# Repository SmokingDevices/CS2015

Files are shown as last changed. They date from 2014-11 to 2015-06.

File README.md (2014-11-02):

Welcome ...

we have started the project!

Also GitHub for Windows installieren
- Links oben mit + das neue Repositorie anlegen (bzw. ein vorhandenes suchen)
- vor Änderungen, immer mit online Synchen (rechts oben)
- Wenn Änderungen, dann über Uncommitted changes diese einchecken
- dann rechts oben sync drücken

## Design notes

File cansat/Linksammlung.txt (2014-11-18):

LINKSAMMLUNG

Staubsensor:
	http://shop.boxtec.ch/grove-staub-sensor-p-41117.html

http://www.pollin.de/shop/dt/NzI2OTgxOTk-/Bauelemente_Bauteile/Aktive_Bauelemente/Sensoren_Peltier_Elemente/Staubsensor_SHARP_GP2U06.html

Kamera:

	http://www.preisvergleich.de/search/landing/query/%2BMicro+%2BCam/s/googlem/koid/2315796613/gkaid/91312190/adid/3319103750/gkyid/32237585990/ckw/2315796613x91312190x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

http://www.nuvolashop.com/en/mini-digital-video-recorders/1781-super-mini-digital-video-audio-recorder-640x480-pixels-camera-usb20-port-micro-sd-card-slot.html

	http://ekonline.co.uk/532-997-thickbox/spy-video-camera-keyring-8gb-micro-sd-card.jpg - http://ekonline.co.uk/deal-of-the-week/532-spy-video-camera-keyring-8gb-micro-sd-card.html

http://www.nacrc.com/d001-mini-dv-camera-without-micro-sd-card-720-x-480px-p-594.html
	
	http://www.aliexpress.com/item/Mini-HD720P-8-0MP-digital-video-camera-without-screen-supports-Micro-SD-card-upto-32GB-built/547477856.html

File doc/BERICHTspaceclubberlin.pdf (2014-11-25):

## Endbericht CanSat 2014

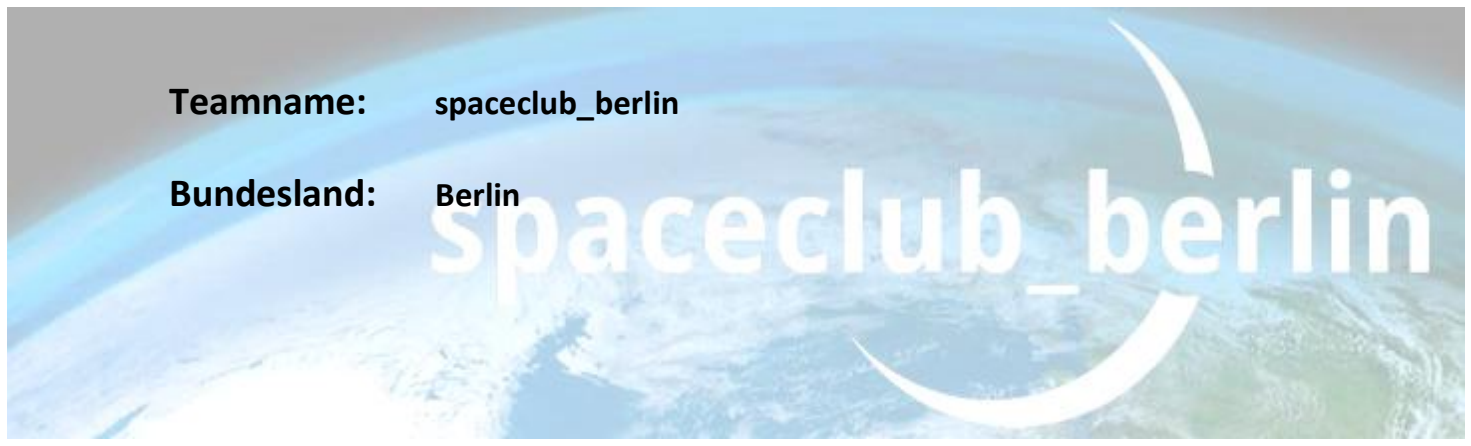
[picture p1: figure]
Teamname:; spaceclub_berlin; Bundesland:; Berlin

1

Inhaltsverzeichnis | Seite
1. | Einleitung | 2
1.1 | Teamorganisation und Aufgabenverteilung | 3
1.2 | Missionsziele | 4
2. | Beschreibung des CanSat | 5
2.1 | Missionsablauf | 5
2.2 | Mechanisches- und Strukturdesign | 6
2.2.1 | Außenkörper | 6
2.2.2 | Innerer Aufbau | 7
2.3 | Elektrische Konstruktion | 11
2.4 | Technische Anforderungen | 14
3. | Ausgangsbedingungen für die Durchführung des Projektes | 17

### 3.1 Physikalische Eigenschaften der Baukomponenten

des CanSat | 17
3.2 | Kosten der verwendeten Baukomponenten | 18
3.3 | Externe Unterstützung | 19
4. | Primäre Mission | 20
4.1 | Missionsziele | 20
4.2 | Dafür benutzte Sensoren bzw. Geräte | 20
4.3 | Ergebnisse | 21
4.3.1 | Temperatursensor | 21
4.3.2 | Drucksensor | 23
5. | Sekundäre Mission | 25
5.1 | Missionsziele | 25
5.2 | Dafür benutzte Sensoren bzw. Geräte | 25
5.3 | Ergebnisse | 26
5.3.1 | Staubsensor | 26
5.3.2 | Kamera mit JPEG-Trigger | 27
6. | Bergungssystem | 28
6.1 | Fallschirm | 28
6.2 | Pieper | 32
6.3 | GPS | 32
6.4 | Bodenstation | 34
6.4.1 | Yagi-Antenne | 34
7. | Fertige Software | 35
8. | Problembehandlung | 45
9. | Öffentlichkeitsarbeit | 47
10. | Reflexion des Wettbewerbes | 49

2

### 1. Einleitung

Unser Team setzt sich aus 3 Mädchen und 2 Jungen zusammen, die sich durch das orbitall im FEZ Berlin und den spaceclub_berlin kennen. Durch gemeinsame Projekte im spaceclub_berlin, aber auch in den Spacecamps 2012 und 2013 oder auch in Jugend forscht, sind wir ein eingespieltes Team geworden. Betreut und unterstützt werden wir von Mitarbeitern des orbitall und erfahrenen Programmierern.
Das Projekt hat uns durch einen Vortrag von Frau Remeikis besonders angezogen. Sie hat uns im spaceclub_berlin detailliert über die Anforderungen des Wettbewerbes informiert und uns dazu animiert, selber daran teilzunehmen. Motiviert uns zu präsentieren und uns neuen Herausforderungen zu stellen, haben wir uns in einem Team von 5 Mitgliedern zusammengefunden. Bei unseren spaceclub-Treffen haben wir uns erstmals an das Thema herangeschlichen und uns beraten, wie wir herangehen wollen. Als nächstes haben wir Mitarbeiter gefragt, unsere Betreuer und Lehrkräfte zu sein und uns über die Technologie des CanSat zu unterrichten. Einige unserer jetzigen Betreuer haben ihre Hilfe zudem selbst angeboten, zum Beispiel auf dem Gebiet des Programmierens. Zu den weiteren Treffen haben wir uns Ziele gesetzt, die wir erreichen wollen, haben uns weitergebildet und gelernt, letztendlich die Komponenten programmiert, konstruiert und zusammengeführt.
Natürlich haben sich während der Zeit viele Probleme aufgetan, die uns viel Zeit gekostet haben. Nichtsdestotrotz haben wir weiter gearbeitet und sind mit Hilfe unserer Betreuer weiter gekommen. Problemszenarien haben wir durchgespielt und sicher gestellt, dass die Startvorbereitung und der Start erfolgreich von statten gehen.
Während der Erarbeitung haben wir viel Material gesammelt und uns mit Experten ausgetauscht. Außerdem wurden wir mit dem Bereich des Programmierens bekannt gemacht und haben die Konstruktion geplant und ausgeführt. Alles mit dem Hintergedanken den Flug erfolgreich durchführen zu können und möglichst wenig Materialschäden davon zu tragen.
Der Wettbewerb startete für uns im Februar 2014 und endet im Oktober 2014 mit dem Start der Rakete und dem Fall des CanSats.
Die Besonderheit unseres CanSats ist die Komplexität der Systeme, die Sekundärmission und unsere Konstruktion. Wir haben nur wenige Komponenten unverändert gelassen und haben somit an viel Platz und Gewicht gespart.

3

### 1.1 Teamorganisation und Aufgabenverteilung

Das Team setzt sich aus uns fünf Teammitgliedern (T1-T5) mit entsprechender Aufgabenverteilung, sowie den Betreuern (B1-B4) und den Helfern (H1- H3) zusammen.

Tabelle 1: Teamorganisation und Aufgabenverteilung
NO | Name | Position
T1 | Christina Nadolsky | Teamleitung; Bau des CanSat; Datengewinnung, Softwareentwicklung
T2 | Yuna Reinhardt | Dokumentation; Kontrolle der Einhaltung der Wettbewerbsbedingungen; Leitung der Testverfahren, Softwareentwicklung
T3 | Adrian Melinat | Fallschirm; Abpufferung des CanSats bei der Landung
T4 | Nana Reinhardt | Bau des CanSat; Datengewinnung, Erstellung der Grafiken, Softwareentwicklung
T5 | Christian Staudigl | Entwicklung der Software, Innere Anordnung der Komponenten
B1 | Sylvia Reinhardt | Betreuerin
B2 | Werner Bachmann | Betreuer, Unterstützung bei der Fallschirmkonstruktion
B3 | Steffen Janke | Berater für die Entwicklung der Software und innere Anordnung der Komponenten
B4 | Jan Klug | Unser Ausbilder für Softwareentwicklung
H1 | Uwe Lathan | Technischer Berater
H2 | Jörg Briesemeister | Beratung bei der Konstruktion
H3 | Jürgen Kittel | Herstellung der Platinen

4

### 1.2 Missionsziele

Der CanSat-Wettbewerb stellt zur Aufgabe, einen Satelliten zu entwickeln, diesen zu bauen und zu programmieren. Er soll zwei Missionen erfüllen, zum einen die vorgegebene Primärmission und zum anderen die selbst wählbare Sekundärmission. Der Satellit wird mit Hilfe einer Rakete auf eine Höhe von bis zu 1000m gebracht und von der Rakete ausgeworfen. Dann fällt der CanSat zurück auf den Boden, wobei er dabei Messungen durchführt.
Bei der Primären Mission ist es unsere Aufgabe, die Temperatur und den Druck zu messen. Das werden wir mit zwei unterschiedlichen Sensoren tun (siehe dazu 4.). Wenn wir die Daten der Temperatur in Höhe von einem Kilometer erhalten haben, werden wir daraus ein Temperaturprofil erstellen. Daraus können wir dann ablesen, wie sehr die Temperaturen in dieser Höhe sich mit denen auf dem Boden unterscheidet und wie sehr sie abfällt / schwankt.

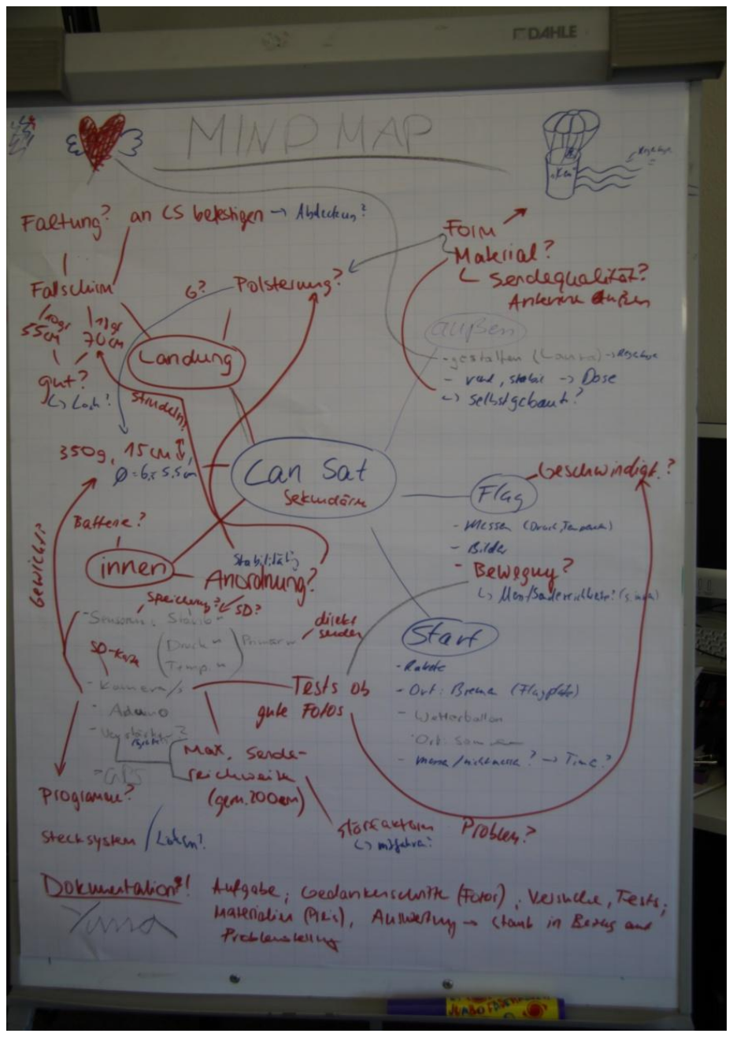
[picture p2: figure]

Bild 1: unser erster Missionsplan für den CanSat

In unserer Sekundären Mission werden wir die Staubkonzentration in der Luft messen. Wir bauen einen Sensor für Ermittlung der Staubkonzentration in der Atmosphäre ein, um diese in Abhängigkeit von der Flugrichtung und Flughöhe zu ermitteln. Gleichzeitig werden wir mit einer Kamera Fotos von dem überflogenen Ort machen, so dass wir die gemessene Staubkonzentration dem Ort (Fabrik, Wald, Autobahn...) zuordnen können. Um die aktuellen Messpunkte noch weiter zu belegen, werden auch die Lagedaten des Satelliten über GPS erfasst. Dies hilft uns auch, den Satelliten zu bergen.

5

### 2. Beschreibung des CanSat

Unser Cansat beinhaltet neben dem CanSat Kit, in dem zwei Temperatursensoren und ein Drucksensor vorhanden sind, verschiedene weitere Bauteile, wie ein Staubsensor, GPS, ein Pieper, und eine Kamera mit Speichermöglichkeit der Bilder auf einem JPEG Trigger (siehe Grafik 1). Die gesendeten Daten der beiden Temperatursensoren, des Drucksensors, des Staubsensors und des GPS werden am Empfängermodul in der Bodenstation mit einer Yagi-Antenne verstärkt. Die Antenne ermöglicht es, Signale aus weiteren Entfernungen besser empfangen zu können.

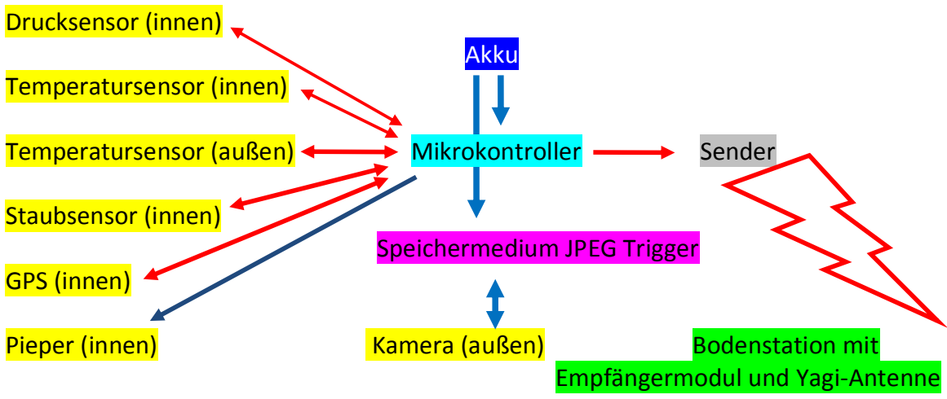
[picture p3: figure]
Drucksensor (innen); Akku; Temperatursensor (innen); Temperatursensor (außen); Mikrokontroller; Sender; Staubsensor (innen); Speichermedium JPEG Trigger; GPS (innen); Pieper (innen); Kamera (außen); Bodenstation mit; Empfängermodul und Yagi-Antenne

Grafik 1: schematische Beschreibung des Aufbaus und der Funktionsweise des CanSat

### 2.1 Missionsablauf

Die Mission wird folgendermaßen ablaufen:
Vor dem Start überprüfen wir die Sensoren, ob sie funktionstüchtig sind. Wir werden die entsprechende Sendefrequenz mit Hilfe des vorgegebenen Programms einstellen. Dann werden wir den Fallschirm überprüfen, ob er beim Transport oder ähnlichem beschädigt wurde und ob er nicht richtig in Position liegt. Sollte dies der Fall sein, wird er ausgetauscht oder richtig positioniert.
Die Notwendigkeit dieser Vorkehrungen beruht auf der Komplexität des CanSat. Da alle Komponenten miteinander in Verbindung stehen, kann der Ausfall einer Komponente zu einem Ausfall fast aller führen. Zum Beispiel wenn die Akkus ausfallen oder auf dem Mikrokontroller ein Kurzschluss entsteht. Wir haben aber sichergestellt, dass sich die Komponenten nicht während des Fluges verändern, sie sind also gepolstert und gesichert. Wichtig ist, dass wir zuerst den Empfänger starten und dann den CanSat, da wir am Anfang der Datenübertragung eine relevante Kopfzeile bekommen.
Der Start des CanSat wird mit einer vorgegebenen Rakete ermöglicht. Der Satellit wird in die Rakete angebracht, der Schalter an der Unterseite des CanSat betätigt, wodurch er zu senden beginnt. Nach ca. 1000 m wird der CanSat von der Rakete gelöst und der Fallschirm geht auf. Nun sinkt er mit einer Fallgeschwindigkeit von 15 Meter pro Sekunde zu Boden. Währenddessen werden die Daten an die Bodenstation gesendet und dort mit einer Yagi-

6

Antenne, die zur Verstärkung des Empfängermoduls angebracht wurde, empfangen. Die Kamera speichert über einen JPEG-Trigger die Bilder auf einer SD-Karte im CanSat.
Die empfangenen GPS-Daten können dann zur Ermittlung der Landestelle genutzt werden, wenn sie sich also über einen längeren Zeitraum nicht mehr ändern und die Höhe des Drucksensors nicht variiert, können wir uns auf die Suche machen. In der Bodenstation müssen nun die gemessenen Daten gespeichert werden. Zur Lokalisation hilft uns ein zweites GPS-Gerät, das mit der Bodenstation verbunden ist. Erkennbar ist der Fallschirm und das glitzernde Wimpel durch grelle Farben und zusätzlich gibt der eingebaute Pieper einen Ton von sich.
Die SD-Karte wird nun entnommen und die darauf gespeicherten Textdateien in Bilder umformatiert. Nun können wir zu den Daten der Sensoren auch Bilder der Umgebung zufügen. Schlussendlich müssen die gemessenen Ergebnisse ausgewertet werden. Diese Auswertung wird dann in unsere Präsentation am Tag nach dem Start mit einfließen.

### 2.2 Mechanisches- und Strukturdesign

Das mechanische- und Strukturdesign setzt sich aus dem Außenkörper und dem inneren Aufbau zusammen.

### 2.2.1 Außenkörper

Anfangs hatten wir uns für einen Außenkörper aus Carbonfaser entschieden. Die Röhre aus diesem Material ist sehr stabil, hatte jedoch den Nachteil, dass ihr Durchmesser nur 60mm war und wir somit auf die Maße (Höhe x Durchmesser) von 115mm x 60 mm kamen. Bei dem Bau des CanSat und der Unterbringung der verschiedenen Bauteile konnten wir nicht auf die fehlenden 6mm verzichten. Die Unterbringung des JPEG-Triggers und der Staubsensors war in dieser engen Röhre nicht möglich, so dass wir uns für ein anderes Material für die Außenhülle des CanSat entschieden haben.
Die Außenhülle ist ein zylindrischer Körper aus Plastik mit den Maßen (Höhe x Durchmesser): 115 mm x 66 mm und zwei Deckeln aus Plexiglas. Sie hat eine milchige Farbe und ist leicht durchlässig (siehe Bild 3).
Der untere Deckel besitzt insgesamt 14 Löcher: darunter 2 Löcher zur Befestigung der inneren Stangen, 3 für den Hauptschalter und seine Befestigung, einen für die Kamera und 5 zur Luftzufuhr für den Staubsensor, welche in einem Kreis angeordnet sind, und eins neben dem Hauptschalter, durch das der NTC (äußerer Temperatursensor) geführt wird.
Der obere Deckel hat 19 Löcher (siehe Bild2). Hierbei handelt es sich um 16, in einem Kreis angeordneten Löcher zur Befestigung des Fallschirms, welcher durch das eine Loch geführt wird und bei dem entsprechenden nebenliegenden Partner hinausgeführt wird. Desweiteren gibt es nur ein Loch für die Luftabgabe, die während des Fluges den CanSat durchströmt. Wir wollen damit einen bestimmen Luftdruck am oberen Deckel entstehen lassen, wodurch dies Luft mit höherer Geschwindigkeit hinaus bläst und der Fallschirm sich möglichst schnell öffnet. Die letzten beiden Löcher sind für zur Befestigung des Deckels mit den inneren Stangen, also für Schrauben vorgesehen.

7

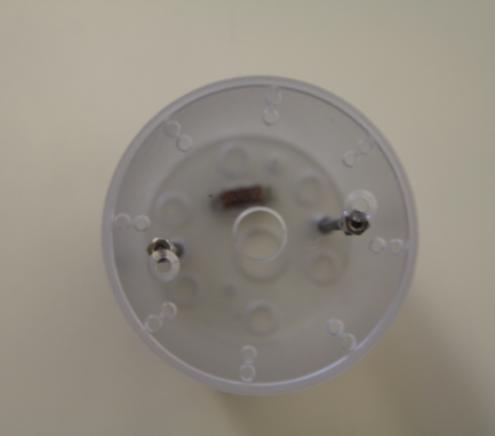
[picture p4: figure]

Bild 2: Oberseite des CanSat mit Durchblick | Bild 3: Seitenansicht des CanSat
zur Unterseite

### 2.2.2 Innerer Aufbau

Der Aufbau des CanSat (siehe Bild 4) basiert auf einem horizontalen Schichtsystem der Komponenten, welche an zwei vertikalen Stangen befestigt sind. Am unteren Teil des CanSat befindet sich unsere Kombination aus Kamera und JPEG-Trigger (siehe Bild5 und Bild6), mit einem großen Loch im unteren Deckel für die Linse der Kamera. Mit einem geringen Abstand von dem JPEG-Trigger wird horizontal darüber der Staubsensor platziert. Die Luft strömt durch die unteren Löcher in den CanSat hinein, durch den Staubsensor und durch die oberen Löcher wieder hinaus. Ebenfalls mit etwas Abstand zur Gewährleistung der Luftzufuhr befindet sich die Dreierkombination aus Sender, Mikrokontroller und Platine mit den Sensoren für Druck, Temperatur (innen), GPS, Pieper und den Anschlüssen zur Stromversorgung der Kamera und des Staubsensors. Der Temperatursensor (außen) ist ebenfalls an der Platine durch lange Kabel befestigt, die nach unten geführt den Sensor neben der Kamera aus einem kleinen Loch am Deckel ragen lassen.
Um Platz zu sparen, werden die Akkus, die ebenfalls mit dem Mikrokontroller verbunden sind, in die Hohlräume zwischen der Dreierkombination gelegt und mit Schaumstoff abgepolstert. Die Elemente sind mit Abstandsschrauben voneinander getrennt. Weitere Polsterungen sind kaum möglich, da der Staubsensor eine ausreichende Luftzufuhr benötigt.

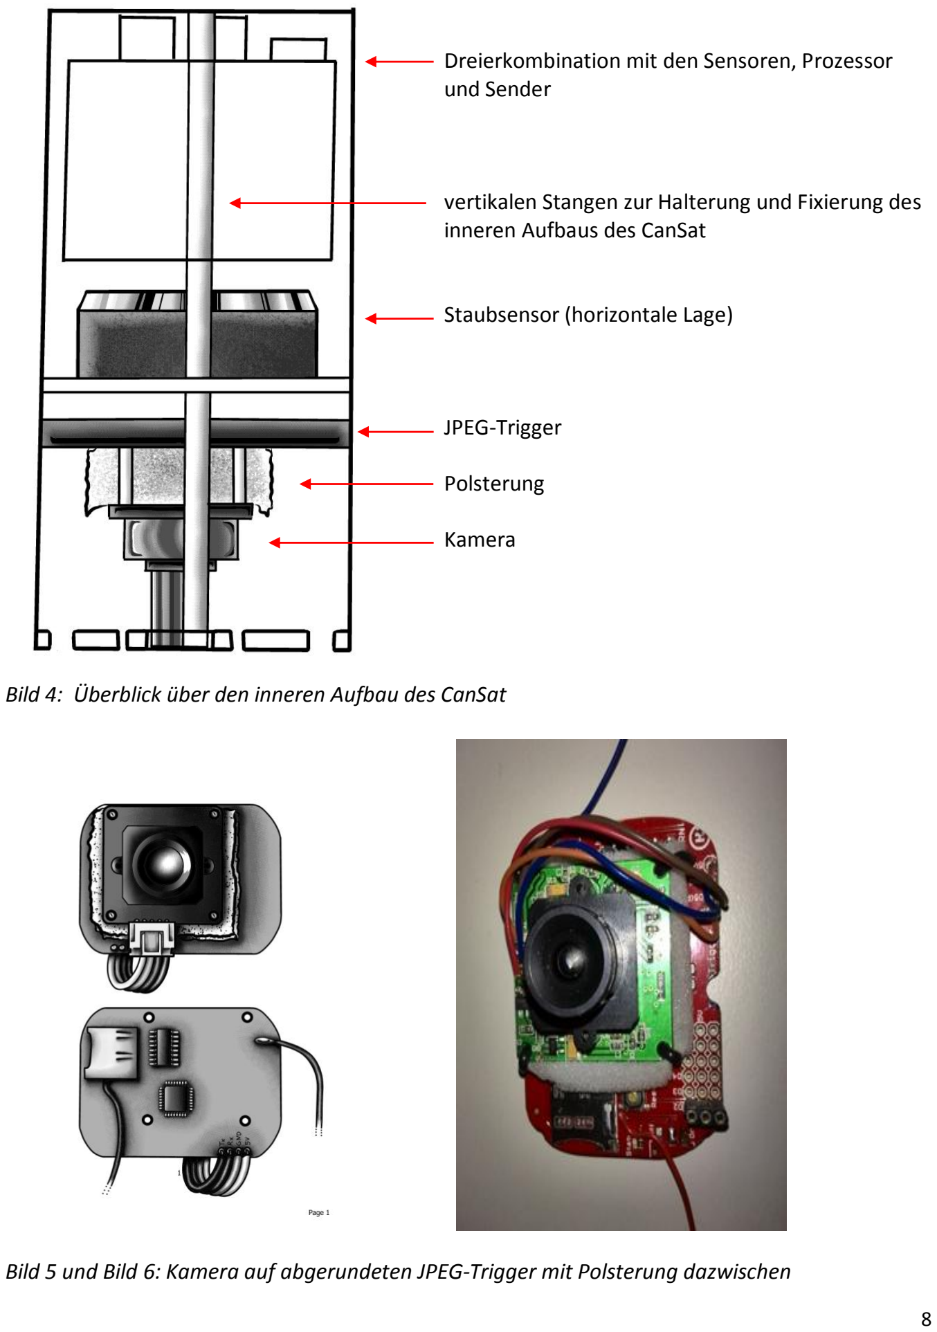
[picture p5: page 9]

8

Dreierkombination mit den Sensoren, Prozessor und Sender

vertikalen Stangen zur Halterung und Fixierung des inneren Aufbaus des CanSat

Staubsensor (horizontale Lage)

JPEG-Trigger

Polsterung

Kamera

Bild 4: Überblick über den inneren Aufbau des CanSat

Bild 5 und Bild 6: Kamera auf abgerundeten JPEG-Trigger mit Polsterung dazwischen

9

Wir haben die Verbindungskabel zwischen Kamera und Trigger aus Platzgründen letztendlich über die Kamera-Platine verlegt, da sonst der Trigger nicht in die CanSat-Hülle gepasst hätte. Die ursprünglich angebrachten Kabel (siehe Bild 5) waren zu sperrig. Außerdem haben wir den JPEG-Trigger nach einer Überprüfung des Leiterplattenschemas an den Ecken abgerundet. Dadurch passt er horizontal in den CanSat-Außenkörper. Durch das Abrunden ist der Schalter, der sich am Trigger befand, nicht mehr vorhanden. Dieser war entbehrlich.

Bild 7 und Bild 8: CanSat seitlich gesehen

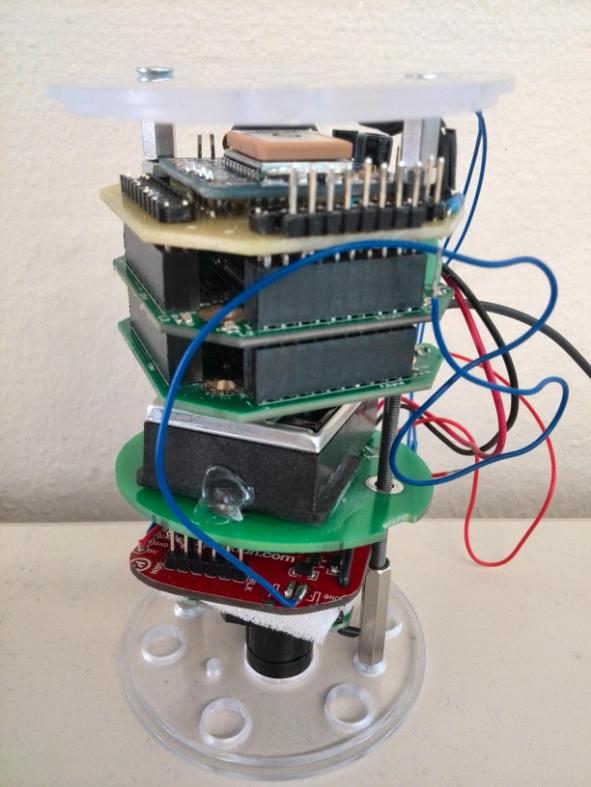
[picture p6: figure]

Das Einfügen des Staubsensors (Bild9) bereitete uns viel Kopfzerbrechen. Er ist in seinen Abmessungen sehr groß (Länge 46.0mm, Breite 30.0mm und Höhe 17.6mm) und nimmt sehr viel Platz im CanSat ein.

Bild 9: Staubsensor mit Anschlussbuchse für die

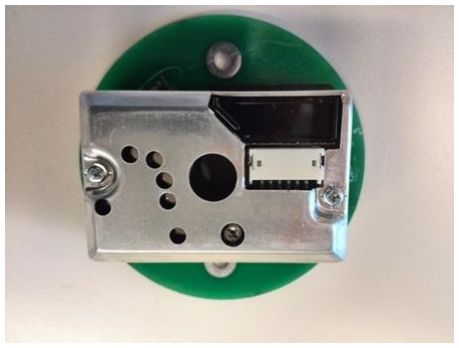
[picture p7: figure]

Kabel und aufliegend auf Platte aus dem original CanSat Kit

10

Die Dreierkombination aus dem CanSat Kit ist nicht mehr im originalen Zustand. Wir haben die obere Platine mit den Temperatursensoren und dem Drucksensor mehrfach entsprechend den aktuellen Notwendigkeiten, nach unseren Vorgaben neu von einem Mitarbeiter des orbitall (H3) anfertigen lassen.

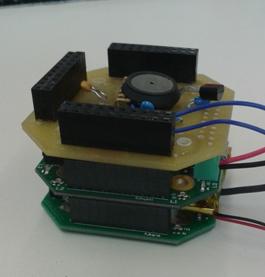
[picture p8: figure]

Bild 10 und Bild 11: erste neue Platine als Bestandteil der Dreierkombination (Platine/Mikrokontroller/Sender) links mit gepolsterten Akku zwischen Mikrokontroller und Sender

Auf der ersten neuen Platine befanden sich die beiden Temperatursensoren und der Drucksensor. Nach Bekanntgabe von Seiten der Wettbewerbsleitung, dass es notwendig ist, einen Pieper und GPS mit in den CanSat zu integrieren, haben wir uns entschlossen, nach unseren Vorgaben eine weitere Platine anfertigen zu lassen und die erste mit dieser auszutauschen. Diese Entscheidung wurde auch auf Grund des geringen Platzverbrauchs einer weiteren Platine gefällt. So wurden auf eine neue Platine alle weiteren Bauteile (zwei Temperatursensoren, Drucksensor, Pieper und GPS) integriert.

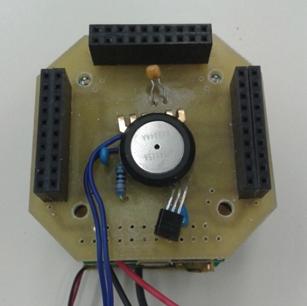
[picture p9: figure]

Bild 12: erste neue Platine mit beiden | Bild 13: zweite neue Platine mit beiden
Temperatursensoren und Drucksensor | Temperatursensoren, ohne Drucksensor, mit Pieper
| und GPS

11

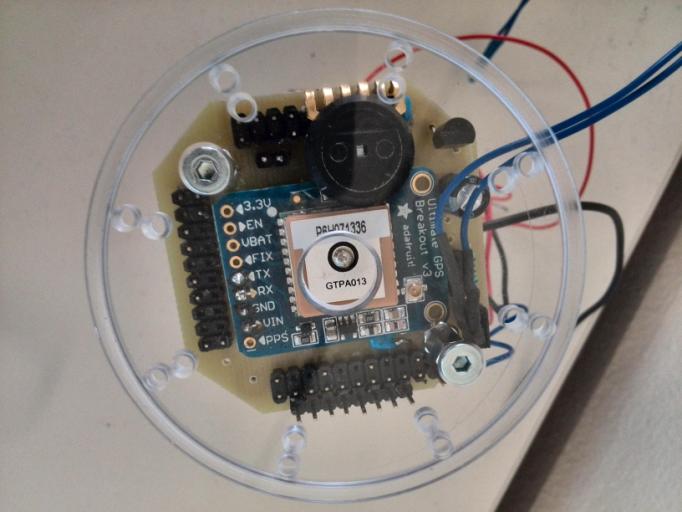
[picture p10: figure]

Bild14: zweite neue Platine mit | Bild 15: CanSat von oben gesehen mit der zweiten
mit beiden Temperatursensoren, | Platine
Drucksensor, Pieper und GPS

### 2.3 Elektrische Konstruktion

Die elektrische Konstruktion haben wir in die Bauteile für die Primärmission (pM1-pM3), die Sekundärmission (sM1-sM2a), die Bergungsmission (bM1 und bM2) und die Energieversorgung (EV) aufgeteilt (siehe Tabelle 2).
Tabelle 2: elektrische Konstruktion des CanSat (Sensoren, Bauteilbezeichnung und Energiebedarf)
NO | Sensor | Bauteilbezeichnung | Energie
pM0 | - | Prozessor und Sendeplatine | 70 mA
pM1 | Temperaturmessung im CanSat | LM35DZ | 10 mA
pM2 | Temperaturmessung außerhalb des CanSat | NTC LE100E3103JB | NTC: Variable, da Widerstand
pM3 | Drucksensor | MPX4115 | 0.2 - 10 mA
sM1 | Staubmessung, Luft kommt von außerhalb des CanSat | Sharp GP2Y1010AU0F | max. 20 mA
sM2 | Kamera | LinkSprite JPEG Color Kamera (seriell) | 10-100 mA
sM2a | Speichermöglichkeit der Bilder | JPEG Trigger | 3,3-5V
bM1 | Pieper | 2 Opes 3V pie200 | 35 mA
bM2 | GPS | GTP A013 | 25 mA
Gesamter Strombedarf | - | - | 280 mA ohne NTC, Trigger, 1,43 h Laufzeit
EV | Akku | Lithium Polymer | 400 mA*h

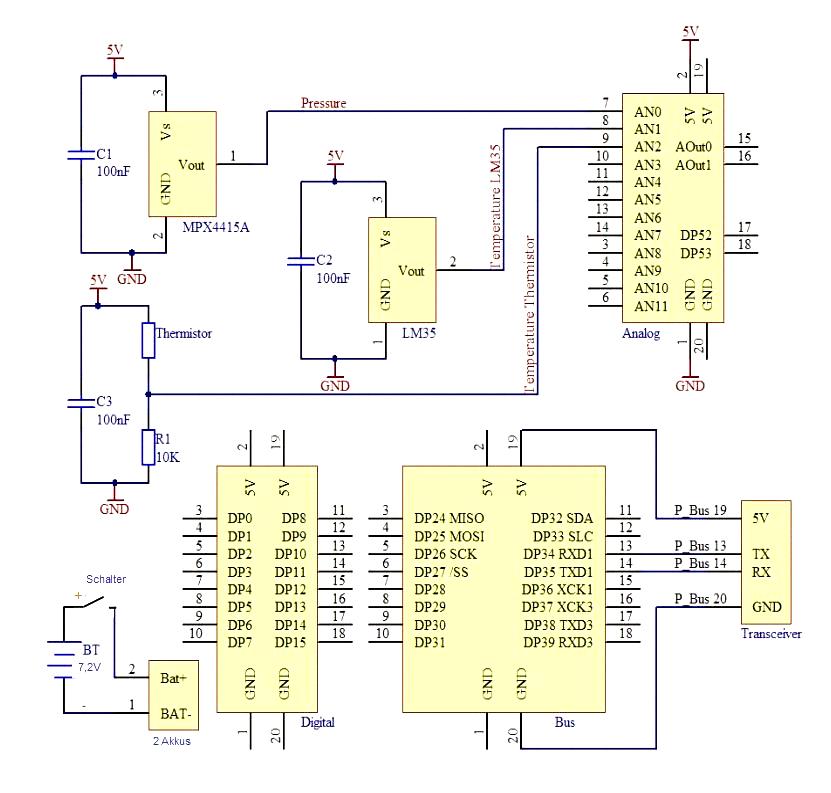
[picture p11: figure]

12

Grafik 2: schematische Beschreibung der elektrischen Konstruktion der Primärmission des CanSat (Anschlussplan der einzelnen Bauteile der Primärmission an der Platine des Mikrokontrollers)
(Quelle: CanSat Kit User Manual, S.30) von uns verändert

Für die Primärmission ist die Belegung der Pins am Mikrokontroller wie folgt:
Drucksensor: | A0
Temperatursensor (innen): | A1
Temperatursensor (außen): | A2

13

Grafik 3: schematische Beschreibung der elektrischen Konstruktion der Sekundärmission des CanSat (Anschlussplan der einzelnen Bauteile der Sekundärmission an der Platine des Mikrokontrollers)

Für die Sekundärmission und das Bergungssystem ist die Belegung der Pins am Mikrokontroller wie folgt:
Staubsensor: | A9, DP2, 5V und GND
Trigger mit Kamera: | nur 5V und GND (Kamera TXD zu RXD) am Trigger,
| Kamera (RXD zu TXD am Trigger)
GPS: | DP37 (RXD3), DP38 (TXD3), 5V und GND
Pieper: | DP5 und GND

14

### 2.4 Technische Anforderungen

In der Tabelle 3 haben wir die Anforderungen an die Konstruktion des CanSat zusammengetragen. Diese wurden in den Wettbewerbsbedingungen vorgegeben und sind einzuhalten.

Tabelle 3: anhand der Wettbewerbsbedingungen vorgegebene technische Anforderungen an die Konstruktion des CanSat

ID | Anforderung | Grund | Priorität | Verweis | Überprüfungs-methoden und Lösung
TA1 | 115 mm Höhe und 66 mm Durchmesser, Zylinder | Wettbewerbs-anforderung | Sehr hoch | Grundlegender Aufbau des CanSat | Messen
TA2 | Bergungssysteme maximal 45mm an oberer Seite überragen | Wettbewerbs-anforderung, sicherer Abwurf | Sehr hoch | Grundlegender Aufbau des CanSat, Bergungssystem | Messen
TA3 | Gewicht: 350 g | Wettbewerbs-anforderung | Sehr hoch | Grundlegender Aufbau, Gewichts-orientierung | Wiegen
TA4 | Keine Geschosse, Feuerwerkskörper, explosive Materialien | Wettbewerbs-anforderung | Sehr hoch | Materialien | Überprüfung der Materialeigenschaften auf mögliche Gefährdung
TA5 | Leicht erreichbare Batterie bzw. Akkus | Wettbewerbs-anforderung | Sehr hoch falls Austausch notwendig | Grundlegender Aufbau des CanSat | Notfalltest Können durch Herausnehmen des Innenlebens ohne Probleme ausgetauscht werden
TA6 | Leicht erreichbarer Hauptschalter | Wettbewerbs-anforderunge | Sehr hoch | Grundlegender Aufbau des CanSat | Notfalltest Von Unterseite erreichbar
TA7 | Wieder-verwendbares Bergungssysteme in Signalfarben, Fallgeschwindigkeit von 15 m/s | Wettbewerbs-anforderung | Sehr hoch | Grundlegender Aufbau des CanSat, Bergungs-systeme | Tests Fallschirm in roter bzw. gelber Farbe
TA8 | Kosten von maximal 500 € (davon 200€ für das CanSat-Kit) | Wettbewerbs-anforderung | Sehr hoch | Materialien | Ausführliche Dokumentation (siehe 3.2)

15

ID | Anforderung | Grund | Priorität | Verweis | Überprüfungs-methoden und Lösung
TA9 | Luftdruck- und Temperatur-sensoren | Wettbewerbs-anforderung | Sehr hoch | Grundlegender Aufbau, Sensoren | Einbau und Überprüfung der Funktionsfähigkeit Mit Mikrokontroller sicher verbunden und Funktionsfähigkeit bestätigt
TA 10 | Keine Fly-Home-Mission | Wettbewerbs-anforderung | hoch | Grundlegender Aufbau | Kein Auslegung des CanSat auf diese Missionsart
TA 11 | Vor Einsatz der Startrakete müssen alle funktionsfähig sein | Wettbewerbs-anforderung | Sehr hoch | | Überprüfung vor dem Start Funktionsfähigkeit vor Oktober bereits sichergestellt
TA 12 | Fallschirm muss Kraft von 1000 N aushalten | Wettbewerbs-anforderung | Sehr hoch | Fallschirm | Tests
TA 13 | Maximale Flugzeit 120 s | Wettbewerbs-anforderung | Sehr hoch | Voraussagungen des Flugablaufes | Tests, Berechnungen
TA 14 | Glitzernder Wimpel | Wettbewerbs-anforderung | Sehr hoch | Bergungssystem | Tests Anbringung am CanSat
TA 15 | Beschleunigung von 20 g aushalten | Wettbewerbs-anforderung | Sehr hoch | Voraussagung des Flugablaufs und Sicherstellung eines günstigen Ablaufs | Belastungstest mit 70 kg Masse auf die Außenhülle für einige Sekunden
TA 16 | Sendequalität durch Außenmaterial nicht beeinflusst | Zur Sicherung guter Daten | Sehr hoch | Grundlegender Aufbau des CanSat | Test Sender innerhalb der Hülle und erfolgreiches Senden
TA 17 Sendekabel außen | | Zum optimalen Senden der Daten | Sehr hoch | Grundlegender Aufbau des CanSat | Beachtung während des Baus
TA 18 | Akustisches Signal | Leichtes wiederfinden des CanSat | Sehr hoch | Bergungssystem | Test Anbringung eines Piepers innerhalb des CanSats

16

ID | Anforderung | Grund | Priorität | Verweis | Überprüfungs-methoden und Lösung
TA 19 | Speichermöglichkeit (SD-Karte) | Um Bilder zu Speichern | hoch | Grundlegender Aufbau des CanSat | Einbringung der SD-Karte in den CanSat für die Fotos
TA 20 | Leichte Austauschbarkeit der Fallschirme | Um je nach Witterungs-bedingung zu reagieren oder bei Funktions-untauglich-keit des ersten Fallschirms | hoch | Grundlegender Aufbau des CanSat | Beobachtung während des Baus, Anbringung und Entfernen des Fallschirms ohne großen Zeitaufwand
TA 21 GPS | | Leichtes Wieder-finden des CanSat | ratsam | Bergungs-system | Tests der Funktionsfähigkeit

17

### 3. Ausgangsbedingungen für die Durchführung des Projektes

Unser CanSat-Bau wird sowohl durch die physikalischen Eigenschaften der Baukomponenten (pB1-pB10), als auch durch die Kosten der verwendeten Baukomponenten beeinflusst.

### 3.1 Physikalische Eigenschaften der Baukomponenten des CanSat

Bei dem Bau des CanSat muss beachtet werden, dass er ein Gewicht von 350g nicht über- oder unterschreitet. Außerdem können nicht zu große Bauteile verwendet werden, weil sie sonst nicht in die Außenhülle des CanSat passen. Die Beschaffung der Baukomponenten für den Cansat war für uns dadurch eine große Herausforderung.

Tabelle 4: Masse und Größe der Baukomponenten im CanSat
ID | Bestandteil | Masse in g | Größe in mm
pB1 | 2 Akkus (Lithium Polymer) | 19,0 | 40,0x30,0x3,0
pB2 | selbst gefertigte Platine mit Bauelementen (2Temperatursensoren, 1 Drucksensor, Pieper, GPS) | 23,0 | 50,0x50,0x10,0
pB3 | Zweierkombination aus CanSat Kit (Mikrokontroller/Sender) | 37,0 | 50,0x50,0x25,0
pB4 | Staubsensor Sharp GP2Y1 | 15,0 | 46.0x 30.0x17.6
pB5 | JPEG Trigger | 11,3 | 11,0x40,0x60,0
pB6 | Kamera (LinkSprite JPEG Color Camera TTL Interface) | 11,2 | 32x32x30
pB7 | Fallschirm | 15,0 | 260 (Durchmesser)
pB8 | Außenkörper des CanSat inklusive Befestigungen (Metallstangen) | 96,0 | 115x66
pB9 | Glitzernder Wimpel | 8,0 | 150
pB10 | Restliches Material | 114,5 | dem CanSat angepasst
| insgesamt | 350,0

18

### 3.2 Kosten der verwendeten Baukomponenten

Gemäß der Wettbewerbsbedingungen soll der Bau des Cansat Kosten von 500Eur nicht überschreiten.
Tabelle 5: Kosten der Baukomponenten des CanSat
ID | Bestandteil | Preis in €
pB1 | Lithium Polymer (2x) | 16,0
pB2 | selbst gefertigte Platine mit Bauelementen (2Temperatursensoren, 1 Drucksensor) | CanSat-Kit
pB3 | CanSat Kit mit Sensoren (2Temperatursensoren, 1 Drucksensor), sowie Zweierkombination bestehend aus Mikrokontroller und Sender, Metallstangen und Empfänger) | CanSat-Kit 200,00
pB4 | Staubsensor Sharp GP2Y1 | 13,50
pB5 | JPEG Trigger | 27,06
pB6 | Kamera (LinkSprite JPEG Color Kamera) mit 5 Pin Kabel | 43,53
pB7 | Fallschirm | 3,0
pB8 | Außenkörper des CanSat | 10,0
pB9 | Glitzernder Wimpel | 0 ( im Abfall gefunden)
pB 10 | Restliches Material | 0 ( im Abfall gefunden)
pB 11 | GPS-Sender | 38,49
pB 12 | Pieper | 2
pB 13 | verschiedene Kabel | 10,0
pB 14 | Yagi Antenne | 0
| insgesamt | 363,58

19

### 3.3 Externe Unterstützung

Die Räumlichkeiten und das Budget für unser Projekt erhalten wir durch die Kooperation mit dem orbitall, dem Raumfahrtzentrum im FEZ Berlin. Das orbitall führt in Kooperation mit dem DLR den spaceclub_berlin, in dem wir Mitglieder sind. Desweiteren stammen ein Großteil unserer Betreuer aus dem orbitall oder kooperieren anderweitig mit Ihnen. Daher kommt auch das Mitwirken der Sternfreunde im FEZ e.v auf ideeller und motivierender Basis und die Verfügbarkeit einer Yagi-Antenne sowie der Beratung zur Montur und Einsatzfähigkeit durch die JugendTechnikSchule. Während des spacecamps 2014 im orbitall, dem Raumfahrtzentrum im FEZ Berlin, knüpften wir eine Verbindung mit dem Institut für Luft- und Raumfahrt an der TU Berlin, an der ebenfalls CanSats (Nanosatelliten) gebaut werden. Mit Ihnen setzten wir uns in Verbindung bezüglich der Stromversorgung und Kameratechnik, also ebenfalls eine ideelle Kooperation. Während des Spacecamps 2014 verwanden wir „Senseboxen“, die wir anhand einer Veröffentlichung der TU Münster gekauft haben. Bis zu diesem Zeitpunkt war die „Sensebox“ nur stationär benutzbar. Wir nahmen Kontakt zur TU Münster auf und erhielten ein Programm, um diese mobil zu machen. Aus der Programmierung dieser erhielten wir viele Anregungen, z.B. deren Höhenformel war eine besserer Version im Vergleich zu unserer. Materielle Unterstützung erhielten wir auch von Thales Alenia Space Deutschland GmbH.

Partner und Sponsoren

FEZ Berlin (http://www.fez-berlin.de/index.php?id=10)

orbitall, (http://www.fez-berlin.de/index.php?id=3) Raumfahrtzentrum im FEZ Berlin Ansprechpartner: Dr. Sylvia Reinhardt

Thales Alenia Space Deutschland GmbH (https://www.thalesgroup.com/en/content/thales-alenia-space-open-its-german-subsidiary-thales-alenia-space-deutschland-gmbh) Ansprechpartner: Florian Reutter

TU Berlin, Institut für Luft- und Raumfahrt (https://www.ilr.tu-berlin.de/) Ansprechpartner: Cem Avsar (https://www.raumfahrttechnik.tu-berlin.de/menue/ueber_uns/mitarbeiter/dipl-ing_cem_avsar/)

DLR_School_Lab Berlin (http://www.dlr.de/schoollab/desktopdefault.aspx/tabid-1730/10724_read-24165/)
Ansprechpartner: Dr. Christoph Pawek

Uni Münster (http://www.uni-muenster.de/Geoinformatics/gi-at-school/index.html)
GI@School - Institut für Geoinformatik Ansprechpartner: Mario Pesch (http://sensebox.uni-muenster.de/team/)

Sternfreunde im FEZ e.v. (http://www.sifez.de/)
Ansprechpartner: Steffen Janke, Jan Klug

Jugend Technik Schule (http://www.jugendtechnikschule.de/front_content.php)
Ansprechpartner: Sieghard Scheffczyk

20

### 4. Primäre Mission 4.1 Missionsziele

Bei der Primären Mission war es unsere Aufgabe, die Temperatur und den Druck zu messen. Das führen wir mit zwei unterschiedlichen Sensoren durch: der NTC und der LM35 (siehe dazu 4.2). Wenn wir die Daten der Temperatur in Höhe von einem Kilometer erhalten haben, werden wir daraus ein Temperaturprofil erstellen. Daraus erkennen wir die Abhängigkeit der Temperatur von der Höhe. Die dazu benötigte Höhe erhalten wir durch eine Rechnung in der Programmierung. Rund alle 8 Meter verändert sich der Druck um 1 hPa, daher rechnen wir nur den Druck mit der gültigen Höhenformel zur aktuellen Höhe um und senden sie an die Bodenstation. Zusätzlich dazu werden wir die Fallgeschwindigkeit ermitteln - ebenfalls mit einer Formel. Diese kann man aus dem Programm für den Drucksensor entnehmen.
Wir erhalten also in unserem gewählten Zeitabstand die Daten zu: Temperatur außen und Temperatur innen in °C, Druck in hPa, daraus die Höhe in m und die Fallgeschwindigkeit in m/s. Der Grund zur Messung dieser Daten ist die letztendlich die Ermittlung der Flughöhe des CanSat und dessen Fallgeschwindigkeit. Wir messen nicht nur die Temperatur außen, sondern auch innen, um entweder die Isolation der Außenhülle festzustellen oder die Luftzufuhr im CanSat, die benötigt wird um mit dem Staubsensor verwertbare Ergebnisse zu erhalten. Das Zweite liegt bei uns im Vordergrund. Die Fallgeschwindigkeit von 15 m/s wurde von der Wettbewerbsleitung vorgegeben. Durch Ermittlung der Fallgeschwindigkeit können wir entnehmen, ob wir diese Bedingung mit unserem Fallschirm erfüllen konnten.
Zur Gewährleistung der Funktionstüchtigkeit der Sensoren haben wir mehrere Tests durchgeführt.

### 4.2 Dafür benutzte Sensoren bzw. Geräte

Wie im Abschnitt 2.2.2 schon erwähnt, verwenden wir für den Cansat nicht mehr die Originalplatine des CanSat Kits. Auf der ersten neuen Platine befanden sich die beiden Temperatursensoren und der Drucksensor. Auf der zweiten Platine wurde zusätzlich zu den Bauteilen der Primärmission noch Bauteile des Bergungssystems (einen Pieper und GPS) mit untergebracht sowie die Kondensatoren und Wiederstände zur Gewährleistung einer funktionierenden Elektronik.

Tabelle 6: Baukomponenten für die Primärmission des CanSat

NO | Sensor | Bauteilbezeichnung | Energie
pM1 | Temperaturmessung im CanSat | NTC LE100E3103JB | 10 mA
pM2 | außerhalb des CanSat Temperaturmessung | LM35DZ | NTC: Variable, da Widerstand
pM3 | Drucksensor | MPX4115 | 0.2 to 4.8 V Output

21

Demzufolge befindet sich darauf der NTC, der LM35DZ, der MPX4115 und das GPS-Modul, sowie der Pieper.
Zur Messung der inneren Temperatur verwenden wir den LM35DZ und zur äußeren Messung wurde der NTC durch ein langes Kabel nach draußen verlegt. Der Drucksensor wurde umgeklappt und befindet sich demnach auch innen.

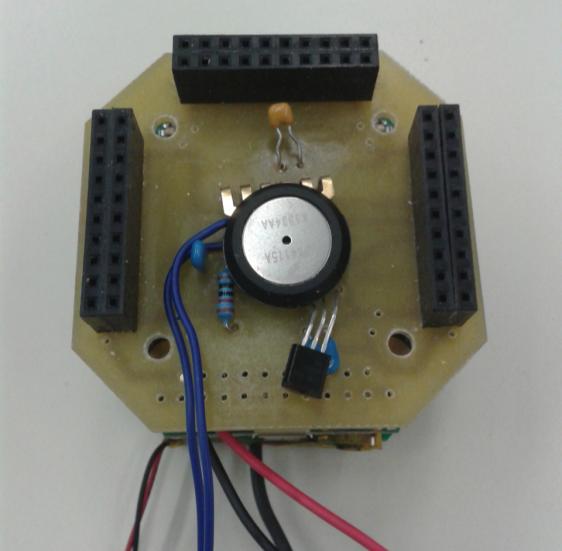
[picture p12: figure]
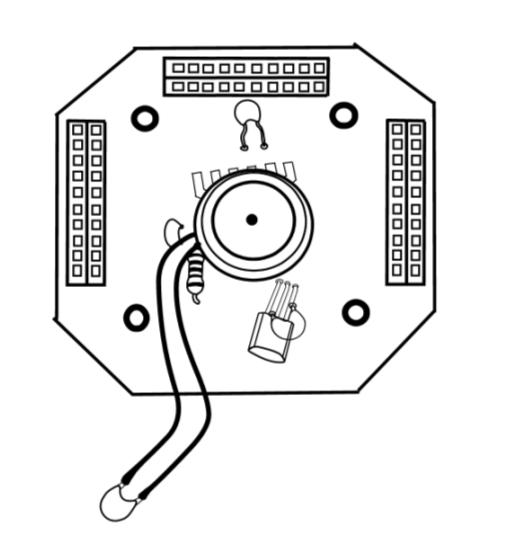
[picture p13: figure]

Bild 16 und Bild 17: erste neue Platine mit beiden Temperatursensoren und Drucksensor

Die folgenden Messungen bzw. Testreihen haben wir mit der ersten neuen Platine durchgeführt.

### 4.3 Ergebnisse

Die Komponenten für die Primärmission wurden getestet und ihre Programmierung fertig gestellt. Wir können damit sicher gehen, dass sie funktionieren und realistische Werte liefern.
Zum Einen testeten wir die Sensoren durch das Legen des CanSat in einen Kühlschrank. Zum Anderen legten wir ihn in eine Vakuumkammer, wodurch wir belegten, dass der Drucksensor funktioniert und die Komponenten selbst niedrigsten Druck aushalten.
Besonders wichtig war jedoch auch, zu wissen, ob die Programmierung auch funktioniert.

### 4.3.1 Temperatursensor

Wir legten den CanSat mit der ersten neuen Platine, die mit den Sensoren für die Primärmission bestückt war für ca. eine halbe Stunde (1700s) in den Kühlschrank.

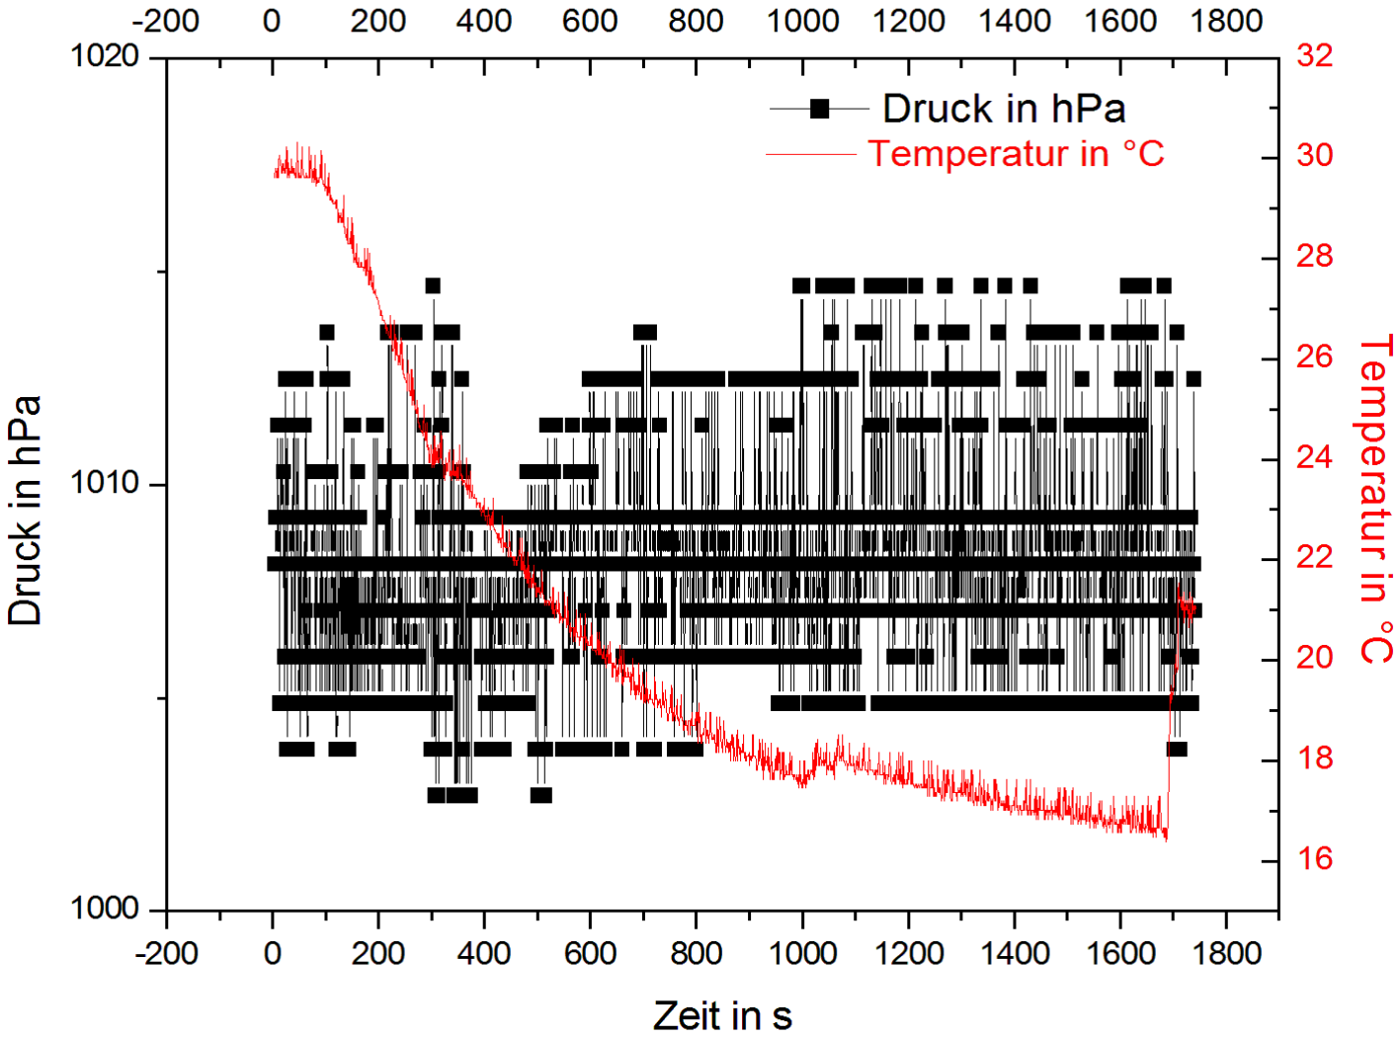
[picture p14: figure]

22

Grafik 4: Test der Primärmission (Druck- und Temperaturmessung im Kühlschrank)

Dieses Diagramm zeigt die Temperatur- und Druckveränderung als Funktion Zeit. Die Temperatur wird in °C, der Druck in hPa und die Zeit in s angegeben. Das Augenmerk liegt hierbei auf dem Temperatursensor (NTC), da wir den CanSat in einen Kühlschrank gelegt haben. Wir erkennen hier ein deutliches Sinken der Temperatur zwischen 0 und 1700 s von ca. 30 auf 16°C. Bei circa 1000 s ereignet sich ein positiver Ausschlag der Temperatur. Hier wurde der Kühlschrank geöffnet und es strömte warme Luft hinein. Nach 1700 s wurde der CanSat wieder aus dem Kühlschrank genommen, nun steigt die Temperatur rapide an.
Daraus schlussfolgern wir zum Einen, dass dieser Temperatursensor realistische Werte anzeigt und funktioniert, jedoch zum Anderen mehr Zeit benötigen um zu erkalten. Also werden die Änderungen ins Negative (Temperatur fällt) langsamer und mit kleinerer Änderungsrate gemessen als die Änderungen ins Positive (Temperatur steigt). In Relation zur Höhe in der sich der CanSat befindet, haben wir demnach keine realistischen Werte, da der Sensor zu lange braucht um die Temperaturunterschiede wahrzunehmen.

Mit dem LM35Dz konnten wir keine Tests durchführen, da dieser über einen längeren Zeitraum kaputt war und noch einige Fehler mit sich bringt.

23

### 4.3.2 Drucksensor

Als weiteren Test der Primärmission legten wir den CanSat mit der ersten neuen Platine, die mit den Sensoren für die Primärmission bestückt war für ca. 5min (300s) in eine Vakuumglocke, wodurch wir belegten, dass der Drucksensor funktioniert und die Komponenten selbst niedrigsten Druck aushalten.

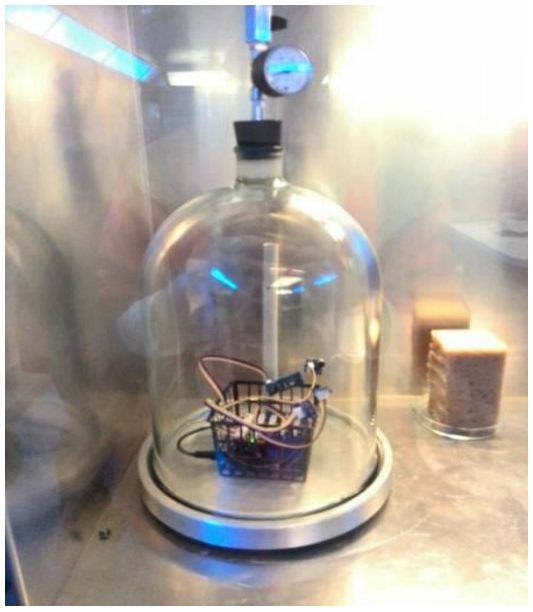
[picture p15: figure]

Bild 18: Test des Drucksensors auf der ersten neuen Platine in einer Vakuumglocke im orbitall

Bei diesem Test haben wir den Drucksensor in eine Vakuumglocke gelegt, den Druck darin verringert und währenddessen die Daten gesammelt. Der blaue Graph zeigt den Druck in hPa an. Man kann sehen, dass sich der Druck am Anfang im normalen Bereich befindet. Nach knapp zwei Minuten fällt der Druck schlagartig ab, in dieser Zeit haben wir die Luft aus der Glocke abgepumpt und dann mit einem Mal wieder rein gelassen, was man an dem plötzlichen Anstieg des Graphen erkennen kann. Das haben wir einmal wiederholt. Im Programm (siehe 4.2) haben wir die Rechnung eingebracht, so dass die Höhe ausrechnet und als Ergebnis mit angegeben wird. Die Höhe in m, in Abhängigkeit vom Druck, wird durch dem grünen Graphen dargestellt. Je niedriger der Druck, desto höher befindet sich der CanSat.

24

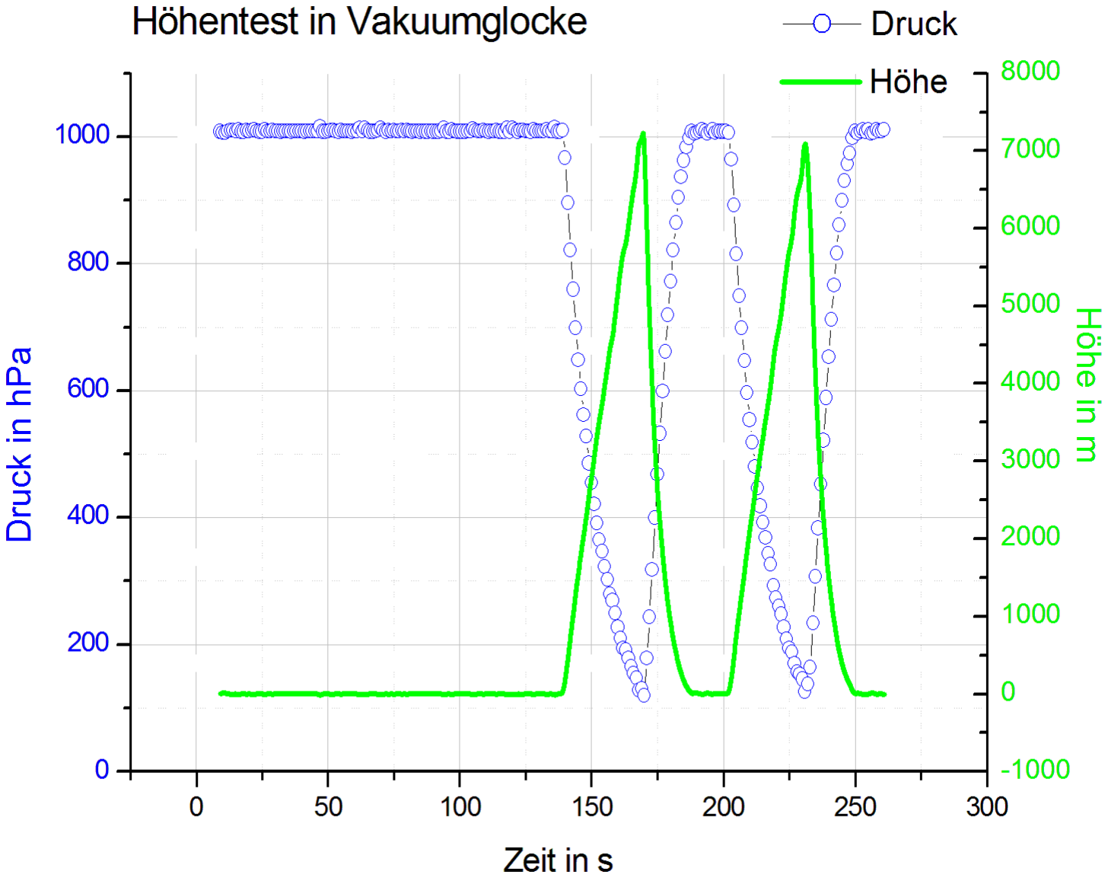
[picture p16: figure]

Grafik5: Test der Primärmission (Druckmessung in der Vakuumglocke)

Hierdurch haben wir festgestellt, dass der Drucksensor gut die Veränderung des Druckes wahrnehmen kann und realistische Werte liefert. Ebenfalls ist die Höhenformel richtig und lässt sich auch anwenden. In diesem Versuch haben wir auch die Fallgeschwindigkeit gemessen, die ebenfalls realistisch war. Der zweite Teil der Primärmission ist also auch funktionstüchtig.

25

### 5. Sekundäre Mission

Das Forschungsthema der Sekundären Mission konnten wir frei wählen.

### 5.1 Missionsziele

Die Feinstaubkonzentration in der Luft stellt heute neben der Abgas- und Stickstoffdioxidbelastung eine Bedrohung für die Bronchialsysteme dar. Besonders durch Emissionen aus Kraftfahrzeugen, Kraft- und Fernheizwerken, Öfen und Heizungen in Wohnhäusern oder auch durch Bodenerosionen gelangt Feinstaub in die Luft. Das Bundesumweltamt definierte zur Gewährleistung gesundheitsunschädlicher Luft besondere Richtlinien, die je nach Art des Staubes in Städten eingehalten werden müssen. Ist dies nicht der Fall, müssen bestimmte Maßnahmen getroffen werden. Da Großstädte wie Berlin oder Bremen durch Gewerbe und Industrie geprägte Städte sind und eine ausgebaute Infrastrukturen besitzen, muss die Luftqualität regelmäßig überprüft werden. Ziel unserer Sekundärmission ist die Messung der Staubkonzentration in Abhängigkeit von der Flugrichtung und Flughöhe. Um die Daten einer bestimmten Region zuzuordnen, z.B. Wald, Industriegebiet oder auch Autobahn, werden Fotoaufnahmen gemacht. Um die aktuellen Messpunkte noch weiter zu belegen, werden auch die Lagedaten des Satelliten über GPS erfasst. Der Staubsensor wird uns Daten in µg/m³ senden, die wir im Endeffekt in einem Höhe-Staubkonzentration-Diagramm auswerten und mit aktuellen Daten vergleichen können. Währenddessen nimmt die Kamera Bilder auf und speichert sie auf eine MicroSD-Karte im JPEG-Trigger. Wenn der CanSat auf dem Boden gelandet ist, können wir die MicroSD-Karte entnehmen und die Fotos erhalten.

### 5.2 Dafür benutzte Sensoren bzw. Geräte

Wie im Abschnitt 2.2.2 schon erwähnt, verwenden wir für den Cansat nicht mehr die Originalplatine des CanSat Kit. Wir entwickelten eine zweite Platine, auf der zusätzlich zu den Bauteilen der Primärmission noch Bauteile des Bergungssystems (einen Pieper und GPS) und Bauteile der Sekundärmission (sM1- sM3) mit angeschlossen wurden.

Tabelle 6: Baukomponenten für die Sekundärmission des CanSat

NO | Sensor | Bauteilbezeichnung | Energie
sM1 | Staubmessung | Sharp GP2Y1010AU0F | max. 20 mA
sM2 | Kamera | LinkSprite JPEG Color Kamera | 10-100 mA
sM2a | Speichermöglichkeit der Bilder | JPEG Trigger mit MikroSD-Karte | 3,3-5V
sM3 | GPS | GTP A013 | 25 mA
Energie-versorgung | Akku (2x) | Lithium Polymer | 400 mAh

26

### 5.3 Ergebnisse 5.3.1 Staubsensor

Ein Hauptziel unserer Sekundärmission ist die Messung der Staubbelastung der Luft mit Hilfe eines Staubsensors. Dieser ist das sperrigste Bauteil in dem CanSat. Normalerweise wird der Staubsensor außen angebracht. Wir haben aber uns überlegt, dass es auch möglich ist, den Staub zu messen, indem der Sensor innen angebracht wird und durch große Löcher in dem Außengehäuse des CanSat mit Außenluft, inklusive des Staubes in der Luft, versorgt wird. Dafür mussten wir einen Weg finden, Löcher in die Hülle zu bohren, sodass Luft von außen in den CanSat hinein und wieder herausströmen konnte, damit der Staubsensor die Staubkonzentration seiner Umgebung messen kann. In beide Deckel haben wir die Löcher gebohrt. Jetzt kann die Luft hinein strömen, im Staubsensor nach Staubpartikeln untersucht werden und durch den anderen Deckel wieder entweichen.

Grafik 6: Test des Staubsensors als Teil der Sekundärmission unter verschiedenen Bedingungen

Bei diesem Diagramm haben wir den Staubsensor in verschiedene Umgebungen gebracht. Als Erstes haben wir ihn an den Auspuff eines PKWs, der mit Benzin angetrieben wird, danach an den Auspuff eines LKWs, der mit Diesel angetrieben wird und danach haben wir den rauchenden LKW-Fahrer gebeten in unseren Sensor zu pusten. Die Staubkonzentration, also die Rohdaten die der Sensor liefert, liegt in der Spannweite von 0 - 1024. Die Zeit t wird in Sekunden angegeben.
In der Zeit t1=1744 haben wir den Staubsensor an den Auspuff des PKWs gehalten. An dieser Stelle kann man einen eindeutigen Ausschlag sehen, der Sensor hat also die Staubkonzentration messen können. In den Zeiten t2=2714 und t3=3018 kann man etwas Ähnliches sehen, mit dem Unterschied, dass der Ausschlag größer ist. Der bei der Zeit t3 gemessene Zigarettenrauch hat bei dem LKW-Fahrer für großes Erstaunen gesorgt, da der Ausschlag Werte erreicht, die nah an dem des PKW-Auspuffes liegt. Der Sensor hat also auch hier eine Veränderung der Umweltbedingung gemessen. Zu den gemessenen Daten müssen wir sagen, dass der Sensor Partikel erst ab einer

27

bestimmten Größe messen kann. Das heißt, dass kleinere Teilchen von ihm nicht angezeigt werden und so die Daten zum Teil unvollständig sind. Die Ausschläge gegen Null sind darauf zurückzuführen, dass ein Anschlusskabel aus unserem Testaufbau herausgerutscht war.
Aus diesem Test schlussfolgern wir, dass die Funktionsfähigkeit des Staubsensors gegeben ist. Wir konnten also die Programmierung und den Aufbau verwenden, um realistische Werte zu erhalten. Ebenfalls bemerken wir, dass der Sensor gut auf die sich ändernden Staubkonzentrationen reagiert wodurch wir selbst in der kurzen Flugphase Ergebnisse erhalten müssten.

### 5.3.2 Kamera mit JPEG-Trigger

Ein weiteres Hauptziel unserer Sekundärmission ist die Aufnahme von Bildern des überflogenen Gebietes mit Hilfe einer LinkSprite JPEG Color Kamera und die Speicherung dieser Bilder auf einem JPEG Trigger mit MikroSD-Karte .
Die Kamera ist in den Boden der Außenhülle des CanSat teilweise mit eingearbeitet. Das Objektiv kann so klarere Bilder mit dem Blick zur Erde machen. Durch die Bilder können wir auch im Nachhinein sehen, wie sehr der CanSat getaumelt ist. Außerdem können wir parallel zur ermittelten Staubkonzentration dem untersuchten Ort ein Bild zuordnen und die Umgebung betrachten.
Verbunden ist die Kamera mit Hilfe eines 5 Pin-Kabels mit dem JPEG-Trigger, welcher wiederum abgeschrägt wurde. Erklärung dazu siehe 2.2.2.

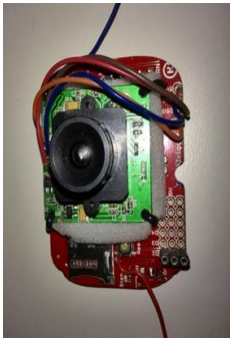
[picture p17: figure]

Bild 19: Hier sieht man noch einmal die Kamera, verbunden mit dem Trigger

28

### 6. Bergungssystem

Unser Bergungssystem besteht aus einem knallig farbigen Fallschirm, einem GPS-Modul und einem Pieper und einem glitzernden Wimpel.

### 6.1 Fallschirm

Um unseren CanSat nicht für die Abwurfversuche zu benutzen, haben wir eine Testdose hergestellt. Als Testdose füllten wir eine normale 0,3l Getränkedose mit flüssigem Lötzinn, bis sie 350g wog. Mit dieser konnten wir dann alle Fallversuche durchführen. Diese fanden auf dem Dach des FEZ-Berlin statt. An der Dose befestigten wir den Fallschirm und zusätzlich noch eine Schnur, um die Dose nach dem Fall wieder nach oben ziehen zu können. Durch diese Versuche konnten wir feststellen, ob der Fallschirm aufgeht und ob wir die vorgeschriebene Fallgeschwindigkeit erreichen. Den letzten Fallversuch führten wir auf dem Aussichtsturm in Woltersdorf (Berlin) durch. Dieser ist größer als das FEZ und daher können wir das Öffnen und den Flug des Fallschirms länger und besser untersuchen.

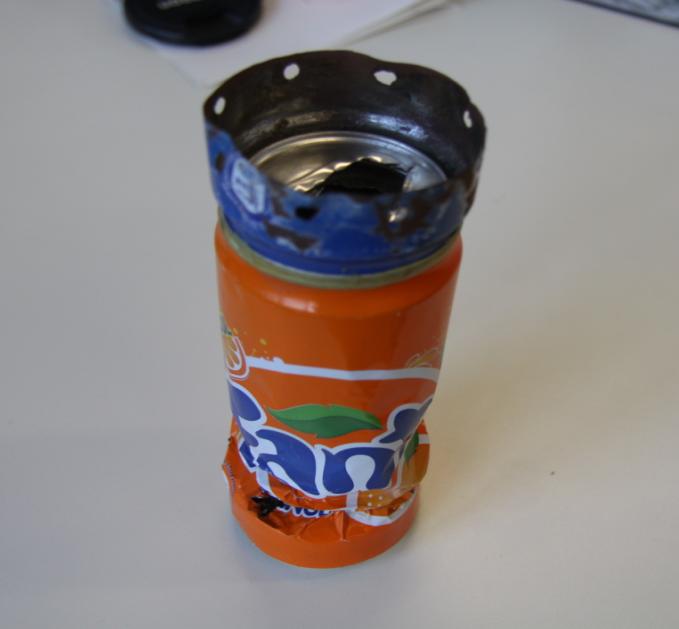
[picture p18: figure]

Bild 20: Testdose für Abwurfversuche mit dem Fallschirm

Die Testdose wurde für mehrere Abwurfversuche benutzt. Sie wurde besonders bei dem Test mit der Fallgeschwindigkeit von ca. 15m/s demoliert.

Die Wahl des Stoffes für den Fallschirm und die Entscheidung der richtigen Fallschirmgröße war auch etwas schwieriger als wir vorher angenommen hatten. Nach vielen Versuchen
haben wir uns für einen kreisförmigen Fallschirm entscheiden, der in seiner Mitte ein Loch hat. Sein Schattendurchmesser beträgt 9,0 cm mit Loch und 7,8 cm ohne das Loch. Zum Testen der Fallgeschwindigkeit nahmen wir den Stoff von fertigen Fallschirmen, den wir zuschnitten und umsäumten, damit dieser nicht ausfranst. Dann haben wir ihn auf der Schattenseite mit Gaze (einem Netz) ausgestattet, um so für Stabilität zu sorgen und um zu verhindern, dass der CanSat sich an den Seilen verheddert und dadurch anfängt zu taumeln.

29

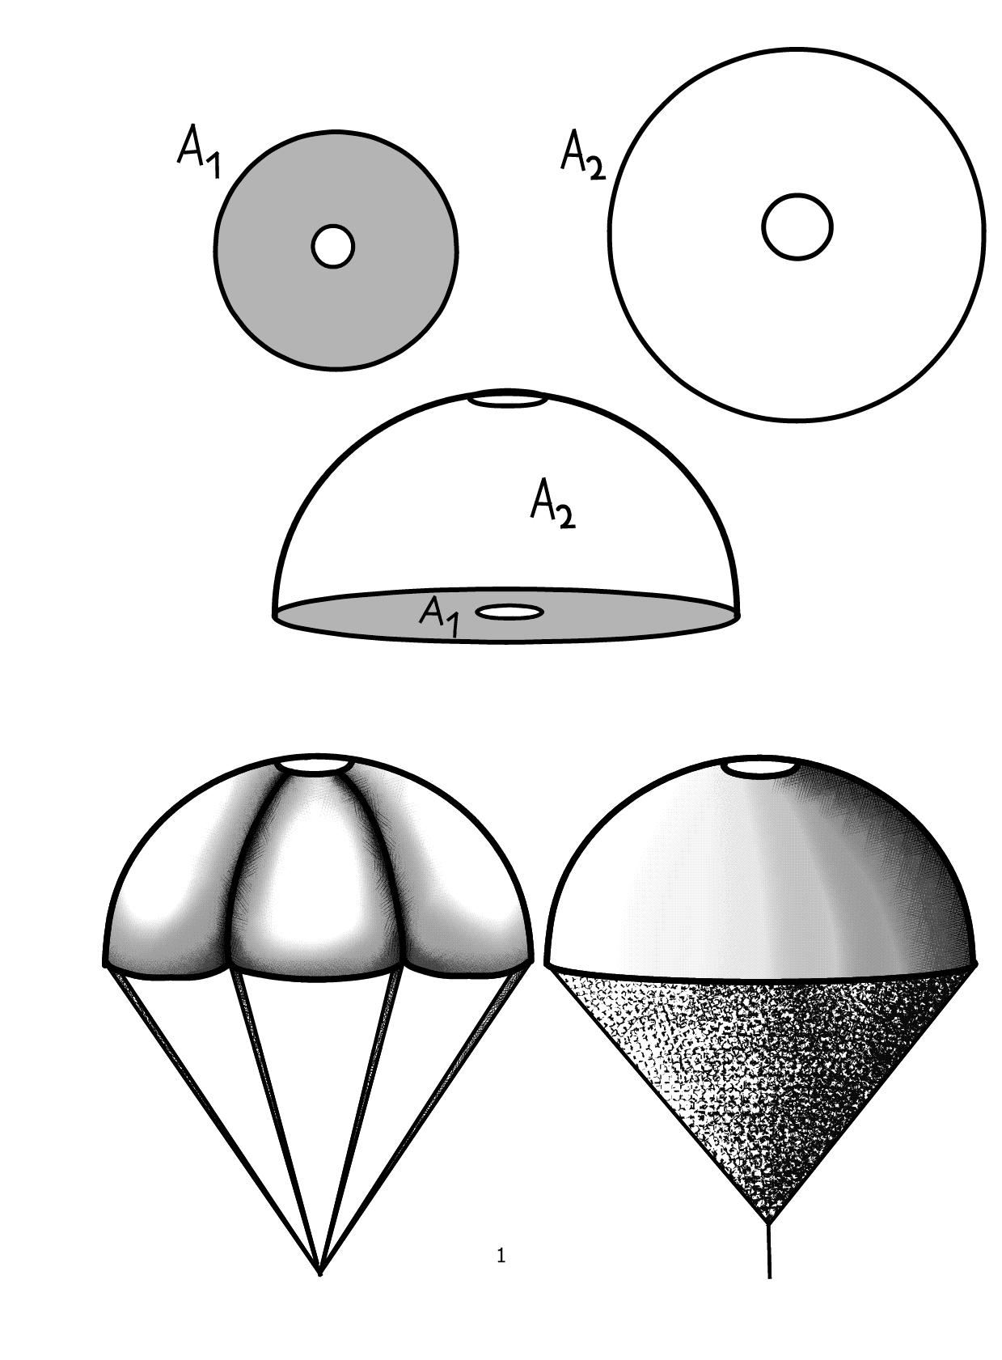
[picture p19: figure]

Bild 21: Schema zur Konstruktion des Fallschirms

30

Bild 22: von uns konstruierter Fallschirm mit Netz

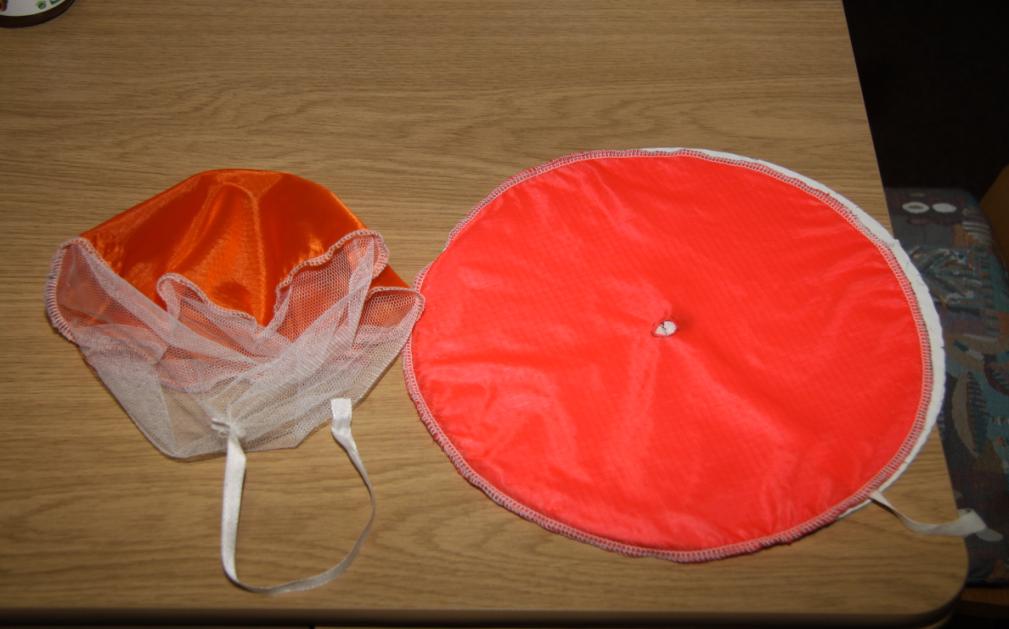
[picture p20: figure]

Bild 23: das sind unsere zwei Fallschirme mit unterschiedlichen Farben

Der Außenhülle des CanSat hat an dem oberen Deckel 16 Löcher, von denen immer zwei dicht aneinander liegen, um die Schnüre des Fallschirms dort gut anzuknoten. Der Fallschirm hat nur eine Schnur, die mittig liegt. An diese werden aber noch acht Schnüre angebracht und diese letztendlich am Cansat befestigt. Der Fallschirm wird in einer Chaosfaltung am CanSat verpackt, gehalten von einem Ring aus feinstem Papier. Beim Abwurf des CanSat wird sich der Fallschirm aus dem Papierring befreien und entfalten. Das Papier zerreißt dabei und fällt zu Boden.

31

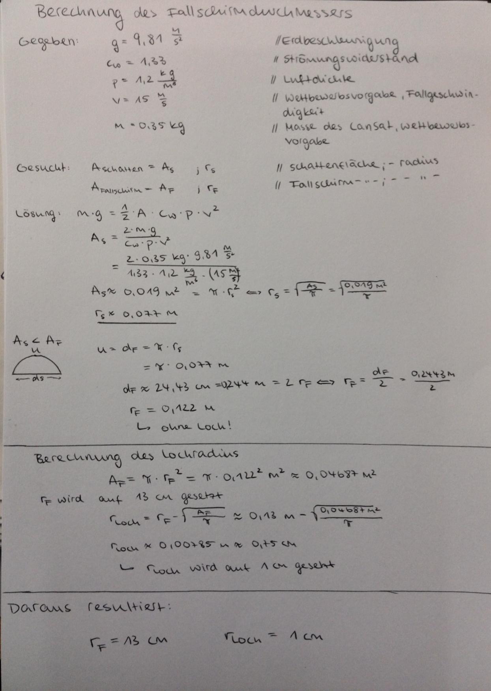
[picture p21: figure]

Bild 24: Berechnung der Fallschirmgröße

32

### 6.2 Pieper

Der Pieper soll uns bei der Bergung des CanSats behilflich sein. Es ist ein winziger Lautsprecher, aufgebracht auf der zweiten neuen Platine, der Pieptöne aussendet. Wir können ihn mit einer beliebigen Melodie ausstatten, die wir im Programm festlegen und je nach Bedarf ändern können.
Wir haben zum Test des Piepers die Titelmelodie von dem Spiel „Super Mario Bros.“ programmiert und damit die Annahme bestätigt. Der Pieper wird bei der Mission entweder ein Piepen in regelmäßigen Abständen oder ein SOS in Morsezeichen erzeugen.

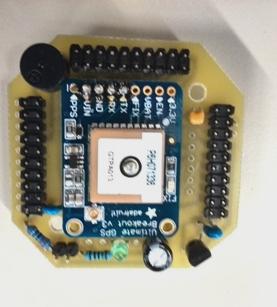
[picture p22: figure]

Bild 25: Pieper (links oben) und GPS-Sender (in der Mitte) auf der zweiten neuen Platine

### 6.3 GPS

Der GPS-Sender wird im CanSat eingebaut. Er wird ebenfalls bei der Bergung nach der Landung behilflich sein. Seine Aufgabe ist es, möglichst genau die Koordinaten der Position des Satelliten zu ermitteln und an die Bodenstation zu senden. Damit können wir aber nicht nur die Position bestimmen, sondern auch, in welcher Höhe sich der CanSat befindet. Diese Information dient lediglich zum Vergleich mit der Höhe, die wir mit dem Drucksensor ausrechnen, um sicher zu gehen, dass der ausgerechnete Wert im Bereich des Möglichen liegt. Wir werden an der Bodenstation einen Computer haben. Dann können wir unsere aktuelle Position herausfinden und die gesendeten Daten eingeben und ermitteln so, in welche Richtung wir gehen müssen, um den CanSat zu bergen. Den GPS-Sender sieht man auf dem Bild 24.

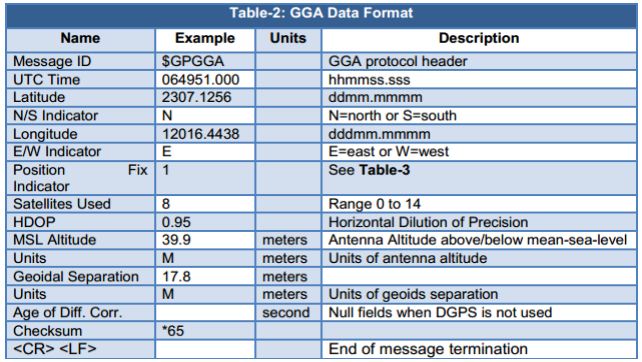
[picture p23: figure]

33

Bild 26: Hier sieht man die gesendeten Daten des GPS-Modules

Wir benötigen jedoch nur die Weltzeit (UTC Time), Breitengrade (Latitude), Nord oder Süd (N/S Indicator), Längengrade (Longitude), Süd oder West(E/W Indicator), Satelliten (Satellites Used), Höhe über Normalnull (MSL Altitude) in m, Geoid-Höhe (Geoidal Separation) in m.

Die Daten können wir betrachten und ermitteln, wie der Cansat sich bewegt hat, z.B. den nördlichsten und südlichsten Punkt zur Betrachtung der horizontalen Bewegung. Außerdem können wir dann die Region feststellen, indem wir die Koordinaten in Google Maps eingeben und uns letztendlich der entsprechende Ort anzeigt wird.

34

### 6.4 Bodenstation

Am Boden werden wir einen Laptop dabei haben, welcher mit Windows 7 arbeitet. Er dient als Datenanzeige, also durch den seriellen Monitor werden uns die gesendeten Daten angezeigt und wir können sie direkt nutzen. Veranschaulicht werden diese in einem Diagramm, das wir mit dem Grafikprogramm „Origin“ bereits vor Ort erstellen können. Somit erhalten wir direkt einen Überblick über die Zustände des Satelliten und seiner Sensoren. Die Empfängerreichweite wird mit Hilfe der Yagi-Antenne verstärkt und wir erhalten die Daten selbst bei großer Entfernung. Zur Bergung des Satelliten wird ein weiteres GPS-Modul an die Bodenstation angeschlossen. Mit diesem können wir dann unsere GPS-Daten auslesen und uns in die Richtung des Satelliten bewegen. Es handelt sich hierbei um den gleichen GPS-Sender wie der im CanSat.

### 6.4.1 Yagi-Antenne

Eine Yagi-Uda-Antenne ist eine Antenne zum Empfangen und Senden elektromagnetischer Wellen. Da der Empfänger an dem Arduino nicht für die Distanz von 1000m ausgelegt ist, verwenden wir eine Yagi-Antenne, die für unsere Frequenzen von 432,99 bis 435,06 ausgelegt ist. Allerdings müssen wir darauf achten, die Antenne immer genau auf den CanSat zeigen zu lassen, sonst bekommen wir keine Daten.
Wir verbinden die Antenne mit dem Empfänger durch ein Koaxialkabel. Der Empfänger befindet sich in einer Schachtel, welche an der Antenne befestigt ist. Wir wählten dafür eine Dose für Blutdruckmessgeräte. Diese kann man aufklappen und kommt somit schnell an den Empfänger heran. Das Verbindungskabel für den PC wurde durch die Außenwand gelegt.

Bild 27: Yagi-Antenne mit Empfänger aus dem CanSat Kit

35

### 7. Fertige Software

1
/******************************************************************* ****************
2 * DEFINITIONEN | *
3
******************************************************************** ***************/
4 #define debug 1 // debug = 1 = Ausgabe auf Serial, = 0 nur Senden
5
6 #define Vcc 5.0 | //Supply voltage
7

8 #define Bitrate 19200
9

10 #define druckPin A0
11 #define tempPin A1 | // int. Sensor LM35 (3 Beine)
12 #define tempNTCPin A2 | // ext. Sensor NTC (2 Beine)
13 #define beepPin 5 | // digitaler D-Pin 5 für Beeper
14 #define dustPin A9 | // angeschlossen an Pin A9
15 #define dustLEDPin 2 | // LED an D-Pin 2 angeschlossen
16

17 // LM35 Temp sensor
18 #define TmpSens 100 | // Sensitivity. Deg.Celsius /volt
19

20 // NTC-sensor variables
21 #define NTC_Grad 18.1699 | // The gradiant value for the NTC sensor
22 #define NTC_Off 21.0 | // The offset value for the NTC sensor
23
24 #define TRENNER "," | // Trennzeichen zwischen den Werten
25

26
/******************************************************************* ****************
27 * VARIABLEN | *

36

28
******************************************************************** ***************/
29 unsigned long letzteSendung = 0;

### 30 int Intervall = 1000; // alle wie viel ms wird eine Messung gemacht und

gesendet

### 31 int TimeSinceStart = 0; // Zeit in Sekunden seit Start des CanSat (Start gleich

einschalten)
32

33 //Primärmission (1)

### 34 int sensorValue = 0; // Variable to store the value coming from the sensor

35 float druckBoden = 0;
36 float druckDurchschnitt = 0; | // Variablen setzen zur späteren Verwendung
37 float hoehe = 0; | // aktuelle Hoehe
38 float altehoehe=0; | // Hoehe bei der letzten Messung
39 float fall= 0; | // aktuelle Fallgeschwindigkeit
40

### 41 boolean ermittleGPS = false; //Wird gerade GPS ermittelt

42

43 // Staubsensor (2)
44 int dustValue = 0; | // Wert der vom Dust Sensor kommt
45 float voltage = 0; | // errechnete Voltzahl

### 46 float dustDensity = 0; // letztendliche Staubkonzentration

47

48 // Pieper einschalten
49 boolean steige = false;
50 boolean unter150 = false; 51

52 //allgemeine Laufvariable
53 int i=0;
54

55 //Header fuer die Exceltabelle, wir nur einmal am Anfang gesendet

### 56 String header = "time,Druck,Temp (int),Temp

(ext),Hoehe,Fallgeschw.,Staubwert,Staubspannung,Staubdichte,GPS Header,Uhrzeit,Latitude,N/S,Longitude,E/W,Position,Satelliten,HDOP,MSL Hoehe,M,Geoid Hoehe,M,Age of Diff,Checksumme";
57

37

58
/******************************************************************* ****************
59 * FUNKTIONEN | *
60
******************************************************************** ***************/
61 //Primärmission (1)

### 62 float getPressure (int pin) { //Methode für Druck

63 // float volt = Bit2Volt(pin); //liest pin ein
64 // float hPa = 10*(volt/(0.009*Vcc)+(0.095/0.009)); //Umrechnung von V zu Pa und dann zu hPa
65 float hPa=0;

### 66 for (int i=1;i<=10;i++) { // 10 Werte mitteln

67 hPa += (float)(((analogRead(pin)/1024.0)+0.095)/0.0009);
68 | // | hPa = hPa+(hPa*0.02); // Sensor Eichung, zeigt immer zu
wenig an

### 69 hPa += 17.0; // Sensor Eichung, Fehler laut Datenblatt linear +17

70 }

### 71 return hPa/10.0; // zurueckgeben

72 }
73

### 74 float getTemperatureIntern(int pin){ //LM35 an A1

75 float volt=0;
76 float result=0;

### 77 for (i=1;i<=5;i++){ // 5 Werte mitteln 78 volt = Bit2Volt(pin); //liest pin ein 79 result +=volt*TmpSens; //umrechnung

80 }

### 81 return result/5.0; // zurueckgeben

82 }
83

### 84 float getTemperatureExtern(int pin){ 85 float volt = Bit2Volt(pin); // liest pin ein 86 float Temp=NTC_Grad*volt-NTC_Off; // umrechnen Volt nach Grad Celcius 87 return Temp; // zurueckgeben

88 }
89

### 90 float Bit2Volt(int n){ // Funktion zum Lesen und umwandeln

38

### 91 int raw = analogRead(n); // Messdaten von pin 'n' lesen 92 float volt = (float)raw*5.000/1023; // Umrechnung für Volt 93 return volt; // zurückgeben der Voltzahl

94 }
95

### 96 float calcAltitude(float pressure){ // rechne Hoehe 97 float A = pressure/druckDurchschnitt; // Gemessener Druck

/Druckdurchschnitt

### 98 float B = 1/5.25588; // B als Konstante einsetzten (aus Datenbank) 99 float C = pow(A,B); // Logarithmus von A und B

100 C = 1 - C;
101 C = C /0.0000225577;
102 return C;
103 }
104

105 String floatToString(float number){ 106 String stringNumber = "";
107 char tempChar[10];
108 dtostrf(number, 4, 2, tempChar); 109 stringNumber += tempChar; 110 return stringNumber;
111 }
112

113 String GetGGA() {
114 //Serial.println("ermittle gga"); 115 String gps_output = "";
116 boolean GGAready = false; 117 boolean start = false;
118 int inByte = 0;
119 char inChar;
120
121 ermittleGPS = true;
122 while (!GGAready) {
123 // Serial.println(millis()); 124 if (Serial3.available()) {
125 inChar = Serial3.read();
126 inByte = int(inChar);
127 | //Serial.print(inChar); | // Debug Ausgabe
128 | //Serial.print(inByte); | // Debug Ausgabe
129 //Serial.print(", "); // Debug Ausgabe

39

130 if (start) {
131 if (inByte==13) { // Abbruch Bedingung erreicht 132 GGAready=true;
133 } else {
134 gps_output += inChar;
135 }
136 } else { // warten auf 10 im Stream, also Ende der Zeile 137 if (inByte==10) {
138 start = true;
139 }
140 }// Ende if (start)
141 } // Ende if (available)
142 }// Ende while
143 ermittleGPS = false;
144 return(gps_output);
145 }
146

147
/******************************************************************* ****************
148 * SETUP ROUTINE | *
149
******************************************************************** ***************/
150 void setup () { //Voreinstellungen
151 pinMode(16, OUTPUT); // init LED Debug beim Einschalten
152 pinMode(17, OUTPUT); // init LED
153 pinMode(18, OUTPUT); // init LED
154 pinMode(19, OUTPUT); // init LED
155 pinMode(20, OUTPUT); // init LED 156 pinMode(21, OUTPUT); // init LED 157 pinMode(22, OUTPUT); // init LED 158 pinMode(23, OUTPUT); // init LED 159 digitalWrite(16, LOW); // set LED on 160 digitalWrite(17, LOW); // set LED on 161 if (debug == 1) {
162 Serial.begin(Bitrate);
163 }
164 digitalWrite(18, LOW); // set LED on
165 Serial1.begin(Bitrate); // Initialisiere das Sendmodul (19200 bits per second):
166

40

167 Serial3.begin(9600); | // init GPS an Serial2
168 // Serial3.println("$PMTK220,100*2F"); // 10 Hz, ging gut mit Arduino, mit T-Board nicht mehr
169 Serial3.println("$PMTK314,0,0,0,1,0,0,0,0,0,0,0,0,0,0,0,0,0,0,0*29"); // Nur GGA ausgeben
170 digitalWrite(19, LOW); // set LED on
171
172 pinMode (beepPin,OUTPUT); | // Piepser zum Laerm
machen
173 pinMode (dustLEDPin,OUTPUT); | // LED des Staubsensor
174

175 digitalWrite(20, LOW); // set LED on
176

177 //Primärmission
178 float hPa;
179 int j = 0;
180 for (int i = 0; i < 20 ; i++) { // Schleife, 20 mal 181 j++;
182 hPa = getPressure(druckPin);
183 if (800 < hPa && 1500 > hPa){
184 //zum Berechnen des 0-Druckes...sollten unwahrscheinliche Werte gemessen werden,
185 //sollen diese ignoriert und durch neue ersetzt werden
186 druckBoden += hPa;
187 } else {
188 i--;
189 }
190 if (j > 50){
191 i = 20;
192 }
193 }
194 digitalWrite(21, LOW); // set LED on
195 druckDurchschnitt = druckBoden/20; // Berechnung des Druckdurchschnittes
196
197 if (debug == 1) { // debugging
198 Serial.print("hPa:");
199 Serial.println(hPa);
200 Serial.print("druckDurchschnitt:");

41

201 Serial.println(druckDurchschnitt); 202 Serial.print("setup done : "); 203 Serial.print(hoehe);
204 Serial.println("m");
205 Serial.println(header);
206 } // Ende debug
207 digitalWrite(22, LOW); // set LED on 208 Serial1.println(header);
209 digitalWrite(23, LOW); // set LED on 210

211 // kurzer Beep beim Einschalten 212 digitalWrite (beepPin, HIGH);
213 delay(100);
214 digitalWrite(beepPin,LOW);
215
216 delay(500); | // warten fuer eine halbe Sekunde
217 digitalWrite(16, HIGH); // set LED off
218 digitalWrite(17, HIGH); // set LED off
219 digitalWrite(18, HIGH); // set LED off
220 digitalWrite(19, HIGH); // set LED off 221 digitalWrite(20, HIGH); // set LED off 222 digitalWrite(21, HIGH); // set LED off
223 digitalWrite(22, HIGH); // set LED off
224 digitalWrite(23, HIGH); // set LED off
225 delay(500); | // warten fuer eine halbe Sekunde
226 digitalWrite(16, LOW); // set LED on
227 digitalWrite(17, LOW); // set LED on
228 digitalWrite(18, LOW); // set LED on
229 digitalWrite(19, LOW); // set LED on 230 digitalWrite(20, LOW); // set LED on 231 digitalWrite(21, LOW); // set LED on
232 digitalWrite(22, LOW); // set LED on
233 digitalWrite(23, LOW); // set LED on
234 delay(500); | // warten fuer eine halbe Sekunde
235 digitalWrite(16, HIGH); // set LED off
236 digitalWrite(17, HIGH); // set LED off
237 digitalWrite(18, HIGH); // set LED off
238 digitalWrite(19, HIGH); // set LED off 239 digitalWrite(20, HIGH); // set LED off 240 digitalWrite(21, HIGH); // set LED off 241 digitalWrite(22, HIGH); // set LED off

42

242 digitalWrite(23, HIGH); // set LED off 243 }
244

245

246
/******************************************************************* ****************
247 * LOOP ROUTINE | *
248
******************************************************************** ***************/
249 void loop () { //Schleife <3
250 if (millis()-letzteSendung >= Intervall) { //Sendeintervall = 1s
251 letzteSendung = millis();
252 TimeSinceStart = letzteSendung / 1000;
253 String output = "";
254

255 // ******************* PRIMÄRMISSION ************************
256 float hPa = getPressure(druckPin);
257 hoehe = calcAltitude(hPa);
258 fall = (altehoehe - hoehe) / (Intervall / 1000) ;
259 altehoehe = hoehe;
260
261 if (TimeSinceStart>100) { // Erst nach 100 Sekunden prüfen, so schnell geht da nix
262 // Steigt die Rakete
263 if (steige==false && hoehe>150){
264 steige = true;
265 }
266 // Fällt der CanSat, unter 150m soll der Piepser dann anfangen.
267 if (unter150 == false && steige==true && hoehe<150){ 268 unter150 = true;
269 }
270 }
271
272 | output += (String)(TimeSinceStart); | // Anzeigen des
Zeitcodes

43

273 output += TRENNER;
274 | output += floatToString(hPa); | // Anzeigen des
Druckwertes
275 output += TRENNER;
276 output += floatToString(getTemperatureIntern(tempPin)); // Anzeigen des Temperaturwertes INT LM35
277 output += TRENNER;
278 | output += floatToString(getTemperatureExtern(tempNTCPin)); | //
Anzeigen NTC Temperaturwert EXT
279 output += TRENNER;
280 output += floatToString(hoehe);
281 output += TRENNER;
282 output += floatToString(fall);
283

284 // ******************* STAUBSENSOR ************************
285 | digitalWrite(dustLEDPin, LOW); | // LED anschalten
286 delayMicroseconds (280);
287 | dustValue=analogRead(dustPin); | // Staubsensor
auslesen
288 delayMicroseconds (40);
289 | digitalWrite(dustLEDPin, HIGH); | // LED ausschalten
290
291 | delayMicroseconds (9680); | // Abklingen,
vermutlich nicht nötig
292
293 | voltage = dustValue *0.0048875; | // umrechnen der
ausgelesenen Daten zu Volt
294 | if (voltage <= 3.5) { | // nicht Linearität des
Sensors beachten
295 dustDensity = voltage /7.5;
296 }
297 else {
298 dustDensity = (voltage-3.5)*2 +0.4; 299 }
300

301 output += TRENNER;
302 | output += (String)(dustValue); | // Darstellen von
gemessener Voltzahl
303 output += TRENNER;
304 | output += floatToString(voltage); | // errechneter Voltzahl

44

305 output += TRENNER;
306 output += floatToString(dustDensity); // letztendliche Staubkonzentration
307

308 // ********************* GPS ***************************** 309 String temp = "";
310 if (!ermittleGPS) {
311 temp = GetGGA();
312 if (!temp.equals("")) { 313 output += TRENNER;
314 output += temp;
315 output += TRENNER;
316 }
317 }
318
319 if (debug == 1) {
320 Serial.println(output); 321 }
322 Serial1.println(output); 323
324 } // Ende im Sekundentakt Senden
325
326 if (unter150){ // ab 150m soll der Pieper sich bemerkbar machen. 327 // Test Beeper
328 digitalWrite (beepPin, HIGH);
329 delay(100);
330 digitalWrite(beepPin,LOW); 331 }
332 } // Ende Loop

45

### 8. Problembehandlung

In der Entwicklungsphase des CanSat kamen viele Probleme mit den Sensoren, der Wahl des Außenmaterials, der Platzaufteilung im Cansat und der Programmierung auf. Trotz dessen haben wir die Probleme gemeistert, die Sensoren perfektioniert und den CanSat so fertiggestellt. Im folgenden Text werden wir jedes einzelne Problem auflisten und unsere Lösungen dazu aufzählen.

Als erstes haben wir uns mit dem Temperatursensor beschäftigt. Dadurch, dass wir die Temperatur innerhalb und außerhalb des Satelliten messen, brauchen wir zwei Sensoren: der LM35 und einen NTC. Der LM35 hatte seltsame Werte angegeben, Temperaturen die 400°C überschritten, was auf einen Defekt zurückzuführen war. Wir wissen bis heute nicht woran das lag, konnten aber das Problem lösen, indem wir ihn einfach durch einen neuen Sensor ersetzt haben. Nun bekommen wir realistische Werte. Ein weiteres Problem stellte die Geschwindigkeit des Erfassens der Daten. Die Sensoren brauchen zu viel Zeit um mitzukriegen, dass sich die
Temperatur um sie herum ändert. Das stellt ein großes Hindernis dar, denn der Fall dauert nur ein paar Sekunden und wir haben auch nur einen Versuch, und wenn die Sensoren nur eine geringe Änderung anzeigen, können wir kein realistisches Temperaturprofil erstellen. Um dies zu beheben, verwenden wir notfalls ein Modell über die Temperaturschwankungen in Relation zur Höhe. Auch wenn hier andere Einwirkungen wie z.B. Winde nicht berücksichtigt werden, kann man es zumindest als Vergleich verwenden.

Die Sensoren waren auf einer Platine angelötet, die wir mit dem CanSat-Kit schon fertig
bekommen haben. Diese Platine war allerdings fehlerhaft gelötet und wir haben falsche Werte damit gemessen. Also haben wir eine neue Platine dafür hergestellt und sie darauf angebracht. Als erstes waren wir zuversichtlich, dass sie jetzt funktionieren würden, haben aber dann bemerkt, dass wir einen falschen Widerstand angelötet haben. Dieser wurde ausgetauscht. Als nächstes haben wir den Drucksensor in Anspruch genommen. Dieser war ebenfalls im Kit enthalten und auch schon auf der Platine raufgelötet. Ihn haben wir auch auf die selbstgemachte Platine gesetzt. Da er aufrecht steht und so unnötig Platz in die Höhe verbraucht, haben wir ihn umgeklappt und Platz für den Rest geschaffen. Auf der neuen Platine haben wir einen neuen Kondensator für den Sensor eingelötet. Der nun gemessene Luftdruck war permanent 50 hPa unter Normaldruck. Wir vermuteten, dass der Kondensator die Schuld daran trug. Auch dieser wurde ausgetauscht. Nun bekamen wir richtige Werte und konnten mit dem Drucksensor abschließen.

Dann nahmen wir den Staubsensor ins Visier. Als er bei uns angekommen ist und wir ihn ausprobieren wollten, bemerkten wir, dass ein bestimmter Stecker fehlte, damit man Kabel anschließen konnte. Das hinderte uns am Weiterarbeiten. Wir haben den Stecker dafür bei einem Elektronikfachhandel erworben und dachten, wir hätten das Problem gelöst. Natürlich wurde uns trotz Vorzeigen des Anschlusses ein falscher Stecker verkauft. Letztendlich haben wir online doch noch das richtige Model gefunden und konnten die notwendigen Tests durchführen.
Ein weiteres Problem stellte die Größe des Sensors dar. Er verbrauchte ungefähr 30% des gesamten Platzes innerhalb des Satelliten. Das konnten wir nur durch die „Verkleinerung“ der anderen Sensoren kompensieren. Der Staubsensor an sich kann nur Partikel ab einer bestimmten Größe messen. Auch wenn es nicht änderbar ist, bleibt diese Schwierigkeit.

46

Die Kamera erhält ihre Befehle über den JPEG-Trigger. Sie macht Bilder und speichert sie, allerdings war die Zeitspanne zwischen den Aufnahmen der Bilder zu groß. Sie hat alle 4 Sekunden ein Bild gemacht, doch bei einer Flugzeit von maximal 120 Sekunden ist dies unproduktiv. Lösen können wir das Problem bisher noch nicht und hinzu kommt, dass nicht ausgeschlossen ist, dass der CanSat viel wackelt, während er hinunter fällt. Dadurch könnten wir eine Mehrheit an verwackelten Bildern erhalten.
Beim Kauf des Triggers haben wir keine guten Erfahrungen gemacht. Wir haben insgesamt 4 Trigger bestellt, wovon 2 von Anfang an nicht funktioniert haben und einer während der Testzeit den Geist aufgegeben hat. Unser Fehler war, dass wir die Kommentare zu dem Produkt nicht beachtet haben, die alle aussagten, der Trigger weise im Laufe der Zeit einen Kurzschluss auf. Letztendlich haben wir einen funktionierenden Trigger rausgesucht. An sich verbrauchte der Trigger außerdem zu viel Platz innerhalb des CanSat. Also haben wir die überschüssigen Verbindungen der Platine abgeschliffen und die Anschlüsse für die Spannung umgelegt. Vorher passte er nur vertikal in den CanSat, jetzt passt er horizontal hinein.

An dieser Stelle haben wir uns weiter mit dem GPS beschäftigt. Erst wollten wir ein anderes Model als das aktuelle nehmen, ein größeres und schwereres: EM-406A. Bei diesem hatten wir allerdings Probleme mit der Software. Der Sender hat sich schwierig bis fast gar nicht programmieren lassen. Trotzdem haben wir es versucht und sind daran fast verzweifelt. Das andere Modell (GTP A013) war kleiner, leichter und vor allem besser zu programmieren. So haben wir an Platz und an Gewicht des gesamten Satelliten gespart.

Dann hatten wir noch das Problem mit dem Akku. Erst wollten wir eine normale 9V Batterie nehmen. Aber diese sind sehr groß und somit unpraktisch. Sie hat ungefähr 1/6 des Platzes innerhalb des CanSat eingenommen. Letztendlich haben wir uns für zwei 3,7V Akkus entschieden. So sparen wir Platz und Gewicht, da diese zu dem leichter sind als die Batterie. Wir führten beide Stromversorgungskabel zusammen und löteten sie an die Platine.

Durch die neue Regelung, dass die Fallgeschwindigkeit 15 m/s betragen soll, mussten wir den Fallschirm dementsprechend optimieren. Wir haben eine Formel zum Berechnen der Schattenfläche. Das Problem dabei war, dass wir Anfangs nicht wussten, dass damit die Schattenfläche berechnet wird. Wir haben also eine Weile mit einem zu kleinen Fallschirm die Test durchgeführt. Nun testen wir mit der richtigen Fläche.
Der Fallschirmstoff muss reißfest, nähbar und stabil sein und dem Luftwiderstand standhalten. Wir testeten mit Fallschirmen, die wir gekauft hatten und passten sie unseren Bedingungen an. Außerdem befestigten wir Gaze (ein Netz) daran, das dazu dient, die vorherigen Schnüre zu ersetzen. Diese haben sich zuvor von dem Fallschirmstoff gelöst und dies bereits nach wenigen Tests mit maximaler Fallhöhe von 20 Meter. Das Netz ist an dem gesamten Umfang des Fallschirm gefestigt und hat sich bei den Tests als optimal herausgestellt.

Bei der Yagi-Antenne kamen wenig Schwierigkeiten auf.
Während wir die ganzen Sensoren programmiert und getestet haben, haben wir parallel nach einem Material für die Hülle des CanSat gesucht. Die Hülle musste stabil sein, mindestens 70Kg aushalten, da während des Falls so viel Gewicht auf die Hülle einwirkt, und sie musste die inneren Geräte vor dem Aufprall so gut es möglich ist schützen. Als erstes kam uns ein Carbon-Rohr in den Sinn, da es die nötige Stabilität besaß und in unseren Augen sich als würdig erwies. Allerdings wäre

47

es bei dem Aufprall höchstwahrscheinlich zersplittert und die Sensoren wären auch kaputt gegangen. Also haben wir uns für eine Hülle aus Plastik entscheiden. Diese ist genauso stabil wie das Carbon-Rohr, mit dem Unterschied, dass es bei dem Aufprall höchstens Risse bekommt, die Sensoren innen aber trotzdem unbeschädigt bleiben. Da die Luftzufuhr gewährleistet sein muss, bohrten wir Löcher in die Deckel oben und unten.

Als nächstes kümmerten wir uns um die innere Polsterung. Wir vermuteten, dass die Sensoren während des Aufpralls aufeinander treffen könnten. Wir mussten demzufolge eine innere Polsterung einbauen, damit dies verhindert wird. Dafür verwenden wir Schaumstoff, der zwischen die Komponenten gelegt wird. Zum Beispiel zwischen den Akkus und den Platinen.

Das größte Problem war die Platzeinteilung. Wie bereits erwähnt, sind viele Komponenten zu groß gewesen, um sie alle einzubauen. Wir haben die Temperatursensoren und den Drucksensor von deren ursprünglichen Platinen abgelötet, zwei neue Platinen hergestellt und sie zusammen mit dem GPS-Sender darauf wieder angelötet. Außerdem haben wir den Trigger abgeschliffen, so dass wir ihn horizontal einbauen konnten. Hierbei wurden alle Kanten abgeschrägt und die Längsseiten gekürzt. Zudem ersetzten wir die große Batterie durch zwei zusammen kleinere Akkus. Diese schieben wir in die vorhandenen Lücken, z.B. zwischen dem Sender und dem Mikrokontroller. Zum Schutz vor Kurzschlüssen etc. polstern wir sie durch Schaumstoff. Dieser wird generell nur in Lücken gegeben um zu polstern und zu stabilisieren. Das Objektiv der Kamera nahm zu viel Platz in der Höhe ein, also haben wir sie in den unteren Deckel eingebaut. Demnach bohrten wir ein abgeschrägtes Loch in den Deckel, in das das Objektiv gesetzt werden kann.

### 9. Öffentlichkeitsarbeit und zukünftige Projekte

Um den Wettbewerb auch an andere Schüler und Schülerinnen weiterzuleiten, ist dieser nicht nur auf unserer Internetseite www.spaceclub-berlin.de vertreten sondern auch auf der Homepage des orbitall www.orbitall-berlin.de. Im spacecamp 2014 war der CanSat-Wettbewerb das Hauptthema. Die Campteilnehmer bauten selber mit einer Sensebox einen CanSat. Mit einem Wetterballon wurden diese dann auf eine Höhe von ca. 50 Meter gebracht. Währenddessen sammelten sie Daten und zeichneten diese auf.
Einen Pressebeitrag zum geplanten Bau des CanSat im spaceclub findet man unter: http://www.jugendtechnikschule.de/upload/pdf/KONTEXIS_48_2014.pdf
All unsere Ergebnisse haben wir am Wochenende des 20. und 21. Septembers 2014 beim Raumfahrtwochenende im FEZ Berlin vorgestellt. Dabei handelt es sich um eine Veranstaltung rund um das Thema Raumfahrt. Dort vertreten ist nicht nur unser spaceclub_berlin, sondern auch das orbitall Berlin und das DLR. Bei dieser Veranstaltung haben unser CanSat und die Satelliten aus Senseboxen aus dem spacecamps 2014 einen ganzen Stand eingenommen. Betreut wird dieser Stand von unserem Team. So haben die Besucher die Möglichkeit sich über das Thema zu informieren und direkt Fragen zu stellen.

48

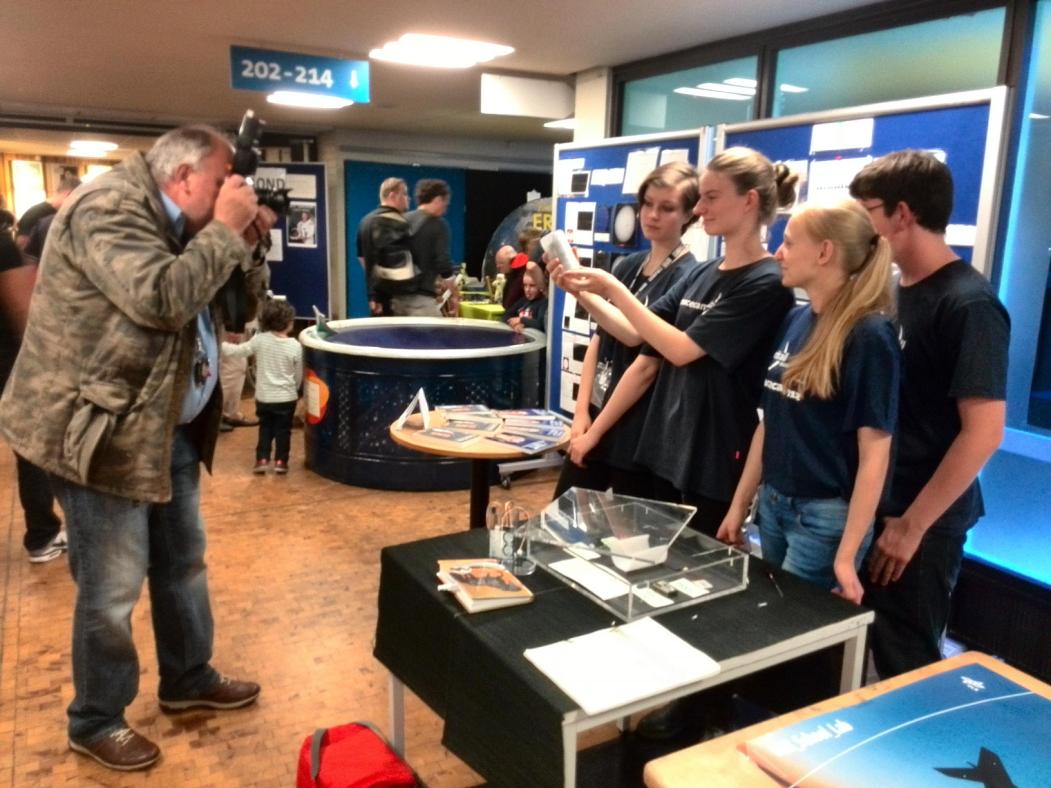
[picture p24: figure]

Bild 28: wir stellten den CanSat zum Raumfahrtwochenende (20.9.-21.9.2014) im orbitall aus, wobei auch Presse anwesend war und mit uns ein Interview durchführte

Im Oktober 2014 werden wir eine modifizierte Sensebox zusammen mit einer Kamera an einen Wetterballon anbringen und diesen in die Stratosphäre fliegen lassen, um auch in dieser Höhe Umweltdaten der Sekundärmission messen zu können.
Eine weitere besondere Aktion findet zur Landung des Philae-Landers am 11.November 2014 statt. Dieser Lander soll im Rahmen der Rosetta-Mission auf dem Kometen Tschurjumow-Gerasimenko landen und dort mehrere Messungen durchführen.
Zusätzlich wollen wir bei Jugend forscht 2015 teilnehmen, da sich dieses Projekt aufgrund des Aufwands und der erlernten Fähigkeiten besonders gut für eine fachliche Arbeit eignet.
Außerdem wird in Kürze ein Mitglied des spaceclub_berlin, Jasper Morse, eine Reportage über das Projekt drehen. Er wird uns darüber auf Englisch interviewen und das Video auf seinem YouTube Kanal veröffentlichen.
Die Ermittlung bzw. Kontrolle der Staubkonzentration in der Luft vor allem in Großstädten, wie z.
B. in Berlin, ist von großer Bedeutung. Zu hohe Staubkonzentrationen belasten die Umwelt und damit auch die Gesundheit der Menschen. Die Messungen werden permanent durchgeführt. In der Labormission des orbitall wird dafür ein Messplatz eingerichtet, an dem Schüler die Möglichkeit haben, aktuelle Messdaten auszuwerten und bewerten zu können. Dafür soll der CanSat permanent über dem Gebäude des orbitall im FEZ Berlin platziert werden. Die gemessenen Daten werden über einen längeren Zeitraum erfasst und mit öffentlich zugänglichen Umweltdaten verglichen. Diese Daten und ihre Auswertung werden 2015 in einer oder zwei Jugend forscht Arbeiten veröffentlicht.

www.orbitall.de
www.spaceclub_berlin.de

49

### 10. Reflexion des Wettbewerbes

Der Wettbewerb war für uns alle eine große Herausforderung. Keiner aus unserem Team hat jemals an so einem großen Gemeinschaftsprojekt mitgearbeitet. So sind wir ohne jegliche Ahnung über die Planung, das Dokumentieren, das Einhalten der Zeit und den eigentlichen Verlauf des Projektes in den Wettbewerb gegangen. Wir haben zu spät angefangen, daran zu arbeiten, was zum Ende hin immer mehr Stress verursacht hat. Wir waren angespannt und hatten die Befürchtung, es nicht rechtzeitig zu schaffen. Das hätten wir wahrscheinlich auch nicht, wenn nicht so viele Leute mitgeholfen und uns betreut hätten. Viele Fachleute aus unserem jetzigem Team sind auf uns zugekommen und haben ihre Hilfe angeboten. Sie haben uns viele Sachen beigebracht und uns in jeder Hinsicht unter die Arme gegriffen. Einige von ihnen kannten wir vorher nicht mal. Durch die enge Zusammenarbeit haben wir uns alle besser oder sogar überhaupt kennengelernt. Es war eine einmalige Erfahrung das Projekt gemeinsam zu Ende zu führen. Nun möchten wir ihnen unser Feedback zum Wettbewerb mitteilen, was wir für gut befunden haben und womit wir nicht zufrieden waren.

Fangen wir mit den positiven Aspekten an. Die Zeit von beinahe einem dreiviertel Jahr war auf jeden Fall ausreichend. In dieser Zeit hat man es gut schaffen können das Projekt zu vollenden und ein vorzeigbares Ergebnis zu erhalten. Außerdem war es eine große neue Herausforderung, die wir hoffentlich gemeistert haben. Die Idee an sich zu einem Wettbewerb zum Bau eines Satelliten zu entwickeln, und damit Jugendliche für Technik und die Erforschung unserer Umweltbedingungen zu begeistern, war äußerst einfallsreich. Außerdem waren die Anforderungen durchaus zu meistern. Sie waren nicht zu hoch gestellt und die Anzahl war ebenfalls im annehmbaren Bereich.

Kommen wir nun zu eher unerfreulichen Seiten des Wettbewerbs. Die Änderungen der Wettbewerbsbedingungen o kurz vor der Abgabe des Endberichtes hat uns viele Male aus der Bahn geworfen. Dadurch, dass zum Beispiel immer wieder neue Fallgeschwindigkeiten festgelegt wurden, mussten wir unseren Fallschirm komplett neu gestalten und zusammenbauen, und das einige Male. War die Geschwindigkeit beim Fallen so hoch angelegt, dass wir zusätzliche Polsterungen einbringen mussten und da viel Zeit in Anspruch nahm. Es wurden auch komplett neue Anforderungen gestellt, wie zum Beispiel der glitzernde Wimpel. Zudem ging der Arduino, der mit dem CanSat-Kit geliefert wurde, kurz vor Schluss kaputt. Aber nicht nur der, sondern beinahe alle Platinen im Kit hatten Fehlfunktionen. Wir waren gezwungen fast jede Platine neu herzustellen und mit dem Rest zu verkabeln, was uns ebenfalls in der Zeit zurück warf. Ein weiterer Punkt stellt der Shop Watterott dar. Wir durften nur bei diesem Shop unsere Sensoren und Materialien einkaufen. Wir haben viele schlechte Ware zugeschickt bekommen. Entweder waren die meisten kaputt oder schlampig gelötet oder sie waren unvollständig. So ging es bei beinahe allen Teilen, die wir dort bestellt haben.

Nicht desto Trotz danken wir Ihnen, das sie uns die Teilnahme an dem Wettbewerb ermöglicht haben und freuen uns, Ihnen unsere Ergebnisse zu präsentieren.

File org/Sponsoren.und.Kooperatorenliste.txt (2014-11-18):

Sponsoren

Orbitall
Jugendtechnikschule
Sternfreunde im FEZ
Geoinformationtechnik an der TU Münster
DLR
FEZ Berlin

Kooperationen
TU Berlin (Cem AVsar)

Vorschläge
Frauenhofer Institut
Geographisches Institut

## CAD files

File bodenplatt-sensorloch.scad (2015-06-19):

difference() {
        
    union () {
        cylinder(2,33,33); //grundplatte
        translate ([0,0,2]) {
            cylinder (2,31,31); //abschlussplatte
        }
    }
        translate ([21,0,-0.5]) {
            cylinder(6,2,2);  //stangenloch
        }
        translate ([-21,0,-0.5]) {
            cylinder(6,2,2);  //stangenloch
        }
        translate ([0,25,-0.5]) {
            cylinder(6,4.5,4.5); //luftloch
        }
        translate ([0,-25,-0.5]) {
            cylinder(6,4.5,4.5);//luftloch
        }
        rotate (45,0,0) {
            translate ([0,-25,-0.5]) {
                cylinder(6,4.5,4.5);//luftloch
            }
            translate ([0,25,-0.5]) {
                cylinder(6,4.5,4.5);//luftloch
            }
        }
        rotate (-45,0,0) {
            translate ([0,-25,-0.5]) {
                cylinder(6,4.5,4.5);//luftloch
            }
            translate ([0,25,-0.5]) {
                cylinder(6,4.5,4.5);//luftloch
            }
        }
        translate([0,0,-0.5]){
            cylinder(6,5,5); //staubsensorloch
        }
    }
// bodenscheibe
    

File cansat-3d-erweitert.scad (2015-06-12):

//beware of easter eggs ;)
translate([0,80,0]) {
difference() {
        
    union () {
        cylinder(2,33,33); //grundplatte
        translate ([0,0,2]) {
            cylinder (2,31,31); //abschlussplatte
        }
    }
    translate([4,5,-1]) {
        cylinder(10,7.5,7.5);
    }
        translate ([21,0,-0.5]) {
            cylinder(6,2,2);  //stangenloch
        }
        translate ([-21,0,-0.5]) {
            cylinder(6,2,2);  //stangenloch
        }
        translate ([0,25,-0.5]) {
            cylinder(6,4.5,4.5); //luftloch
        }
        translate ([0,-25,-0.5]) {
            cylinder(6,4.5,4.5);//luftloch
        }
        rotate (45,0,0) {
            translate ([0,-25,-0.5]) {
                cylinder(6,4.5,4.5);//luftloch
            }
            translate ([0,25,-0.5]) {
                cylinder(6,4.5,4.5);//luftloch
            }
        }
        rotate (-45,0,0) {
            translate ([0,-25,-0.5]) {
                cylinder(6,4.5,4.5);//luftloch
            }
            translate ([0,25,-0.5]) {
                cylinder(6,4.5,4.5);//luftloch
            }
        }
    }
}
//bodenscheibe cansat-alt




difference() {
        
    union () {
        cylinder(2,33,33); //grundplatte
        translate ([0,0,2]) {
            cylinder (2,31,31); //abschlussplatte
        }
    }
        translate ([21,0,-0.5]) {
            cylinder(6,1.5,1.5);  //stangenloch
        }
        translate ([-21,0,-0.5]) {
            cylinder(6,1.5,1.5);  //stangenloch
        }
        translate ([0,25,-0.5]) {
            cylinder(6,4.5,4.5); //luftloch
        }
        translate ([0,-25,-0.5]) {
            cylinder(6,4.5,4.5);//luftloch
        }
        rotate (45,0,0) {
            translate ([0,-25,-0.5]) {
                cylinder(6,4.5,4.5);//luftloch
            }
            translate ([0,25,-0.5]) {
                cylinder(6,4.5,4.5);//luftloch
            }
        }
        rotate (-45,0,0) {
            translate ([0,-25,-0.5]) {
                cylinder(6,4.5,4.5);//luftloch
            }
            translate ([0,25,-0.5]) {
                cylinder(6,4.5,4.5);//luftloch
            }
        }
    }
// bodenscheibe
    
translate([0,0,115]) {
    difference() {
        union() {
            cylinder(2,33,33);
            translate ([0,0,-2]) {
            cylinder (2,31,31); //abschlussplatte
        }
        }
         translate([0,12,0]) {
            cube ([6,7,5],true);//schalterloch
        }
        translate ([21,0,-3]) {
            cylinder(6,1.5,1.5); //stangenloch
        }
       
        translate ([-21,0,-3]) {
            cylinder(6,1.5,1.5); //stangenloch
        }
        translate([0,0,-2.5]) {
            cylinder (6,5,5); //luftloch
        }
        translate ([0,-13,-3]) {
            cylinder (6,2,2); //NTCloch
        }
        rotate (22.5,0,0) {
           translate ([0,22,-3]) {
                cylinder (6,2,2);//schnurloch a
        }
            translate ([0,28,-3]) {
                cylinder (6,2,2); //schnurloch b
        }
        }
        rotate (67.5,0,0) {
           translate ([0,22,-3]) {
                cylinder (6,2,2);//schnurloch a
        }
            translate ([0,28,-3]) {
                cylinder (6,2,2); //schnurloch b
        }
        }
        rotate (157.5,0,0) {
         translate ([0,22,-3]) {
                cylinder (6,2,2);//schnurloch a
        }
            translate ([0,28,-3]) {
                cylinder (6,2,2); //schnurloch b
        }
        }
        rotate (-67.5,0,0) {
          translate ([0,22,-3]) {
                cylinder (6,2,2);//schnurloch a
        }
            translate ([0,28,-3]) {
                cylinder (6,2,2); //schnurloch b
        }
        }
        rotate (-22.5,0,0) {
         translate ([0,22,-3]) {
                cylinder (6,2,2);//schnurloch a
        }
            translate ([0,28,-3]) {
                cylinder (6,2,2); //schnurloch b
        }
        }
        rotate (202.5,0,0) {
         translate ([0,22,-3]) {
                cylinder (6,2,2);//schnurloch a
        }
            translate ([0,28,-3]) {
                cylinder (6,2,2); //schnurloch b
        }
        }
        rotate (112.5,0,0) {
          translate ([0,22,-3]) {
                cylinder (6,2,2);//schnurloch a
        }
            translate ([0,28,-3]) {
                cylinder (6,2,2); //schnurloch b
        }
        }
        rotate (-112.5,0,0) {
          translate ([0,22,-3]) {
                cylinder (6,2,2);//schnurloch a
        }
            translate ([0,28,-3]) {
                cylinder (6,2,2); //schnurloch b
        }
        }
    }
}
//deckscheibe

translate([21,0,1]) {
    cylinder (115,1.5,1.5);
}
translate ([-21,0,1]) {
    cylinder (115,1.5,1.5);
}
//stangen

rotate (45,0,0) {
   translate ([0,0,109]) {
    difference() {
        cube ([49,49,10],true);//platine
        rotate (-45,0,0) {
            translate([0,38,0]) {
                cube ([18,18,19],true);//ecke(y)
            }
            translate ([0,-38,0]) {
                cube ([18,18,19],true); //ecke(-y)
            }
            translate ([38,0,0,]) {
                cube ([18,18,19],true);//ecke (x)
            }
            translate ([-38,0,0]) {
                cube ([18,18,19],true);//ecke(-x)
            }
        }
    }
} //gps
translate ([0,0,98]) {
    difference() {
        cube ([49,49,10],true);//platine
        rotate (-45,0,0) {
            translate([0,38,0]) {
                cube ([18,18,19],true);//ecke(y)
            }
            translate ([0,-38,0]) {
                cube ([18,18,19],true); //ecke(-y)
            }
            translate ([38,0,0,]) {
                cube ([18,18,19],true);//ecke (x)
            }
            translate ([-38,0,0]) {
                cube ([18,18,19],true);//ecke(-x)
            }
        }
    }
}//temperatur
translate ([0,0,83]) {
    difference() {
            cube ([49,49,2],true);//platine
        rotate (-45,0,0) {
            translate([0,38,0]) {
                cube ([18,18,11],true);//ecke(y)
            }
            translate ([0,-38,0]) {
                cube ([18,18,11],true); //ecke(-y)
            }
            translate ([38,0,0,]) {
                cube ([18,18,11],true);//ecke (x)
            }
            translate ([-38,0,0]) {
                cube ([18,18,11],true);//ecke(-x)
            }
        }
    }
    translate([0,20,5])  {
    cube ([26,5,8],true); //pinleiste(y)
    }
    translate([0,-20,5])  {
    cube ([26,5,8],true); //pinleiste(-y)
    }
    translate([20,0,5])  {
    cube ([5,26,8],true); //pinleiste(x)
    }
    translate([0,0,2]) {
    cube ([34,34,2],true); //besetzter platz
    }
    translate([-23,11,0]) {
        cube ([5,5,8]); //stromanschluss-plastik-dingens
    }
}//computer(processor)
translate ([0,0,72]) {
    difference() {
            cube ([49,49,2],true);//platine
        rotate (-45,0,0) {
            translate([0,38,0]) {
                cube ([18,18,11],true);//ecke(y)
            }
            translate ([0,-38,0]) {
                cube ([18,18,11],true); //ecke(-y)
            }
            translate ([38,0,0,]) {
                cube ([18,18,11],true);//ecke (x)
            }
            translate ([-38,0,0]) {
                cube ([18,18,11],true);//ecke(-x)
            }
        }
    }
    translate([0,20,5])  {
    cube ([26,5,8],true); //pinleiste(y)
    }
    translate([0,-20,5])  {
    cube ([26,5,8],true); //pinleiste(-y)
    }
    translate([20,0,5])  {
    cube ([5,26,8],true); //pinleiste(x)
    }
    translate([0,0,2]) {
    cube ([34,34,5],true); //besetzter platz
    }
}//SDkarte
translate ([0,0,61]) {
    difference() {
            cube ([49,49,2],true);//platine
        rotate (-45,0,0) {
            translate([0,38,0]) {
                cube ([18,18,11],true);//ecke(y)
            }
            translate ([0,-38,0]) {
                cube ([18,18,11],true); //ecke(-y)
            }
            translate ([38,0,0,]) {
                cube ([18,18,11],true);//ecke (x)
            }
            translate ([-38,0,0]) {
                cube ([18,18,11],true);//ecke(-x)
            }
        }
    }
    translate([0,20,5])  {
    cube ([26,5,8],true); //pinleiste(y)
    }
    translate([0,-20,5])  {
    cube ([26,5,8],true); //pinleiste(-y)
    }
    translate([20,0,5])  {
    cube ([5,26,8],true); //pinleiste(x)
    }
    translate([0,0,2]) {
    cube ([34,34,2],true); //besetzter platz
    }
}//sender
//platinen

translate ([0,0,11]) {
    rotate (60,0,0) {
        difference() {
            cube([46,34,18],true);
            cylinder (18,4,8);
        }
    }
}
//staubsensor


rotate(-110,0,0) {
translate([-3,28,23]) {
     cube([18,1,42],true); //platine
    translate([0,4,9]) {
        cube ([8,8,8],true);//kamera-linse
    }
    translate ([-6,-8.5,-6]) {
        cube ([15,8,27]);//akku
    }
}
}//kamera
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

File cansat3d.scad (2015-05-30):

difference() {
        cylinder(2,33,33);
        translate ([21,0,-0.5]) {
            cylinder(3,3,3);  //loch
        }
        translate ([-21,0,-0.5]) {
            cylinder(3,3,3);  //loch
        }
        translate ([0,25,-0.5]) {
            cylinder(3,4.5,4.5);
        }
        translate ([0,-25,-0.5]) {
            cylinder(3,4.5,4.5);
        }
        rotate (45,0,0) {
            translate ([0,-25,-0.5]) {
                cylinder(3,4.5,4.5);
            }
            translate ([0,25,-0.5]) {
                cylinder(3,4.5,4.5);
            }
        }
        rotate (-45,0,0) {
            translate ([0,-25,-0.5]) {
                cylinder(3,4.5,4.5);
            }
            translate ([0,25,-0.5]) {
                cylinder(3,4.5,4.5);
            }
        }
    }
// bodenscheibe
    
translate([0,0,115]) {
    difference() {
        cylinder(2,33,33);
        translate ([21,0,0]) {
            cylinder(3,3,3); //loch
        }
        translate ([-21,0,0]) {
            cylinder(3,3,3); //loch
        }
        translate([0,0,1]) {
            cylinder (3,5,5);
        }
        translate ([0,-15,1]) {
            cylinder (3,2,2);
        }
        rotate (22.5,0,0) {
            translate ([0,26,1]) {
                cylinder (3,1,1);
            }
            translate ([0,29,1]) {
                cylinder (3,1,1);
            }
        }
        rotate (67.5,0,0) {
            translate ([0,26,1]) {
                cylinder (3,1,1);//schnurloch a
        }
            translate ([0,29,1]) {
                cylinder (3,1,1); //schnurloch b
        }
        }
        rotate (157.5,0,0) {
            translate ([0,26,1]) {
                cylinder (3,1,1);//schnurloch a
        }
            translate ([0,29,1]) {
                cylinder (3,1,1); //schnurloch b
        }
        }
        rotate (-67.5,0,0) {
            translate ([0,26,1]) {
                cylinder (3,1,1);//schnurloch a
        }
            translate ([0,29,1]) {
                cylinder (3,1,1); //schnurloch b
        }
        }
        rotate (-22.5,0,0) {
            translate ([0,26,1]) {
                cylinder (3,1,1);//schnurloch a
        }
            translate ([0,29,1]) {
                cylinder (3,1,1); //schnurloch b
        }
        }
        rotate (202.5,0,0) {
            translate ([0,26,1]) {
                cylinder (3,1,1);//schnurloch a
        }
            translate ([0,29,1]) {
                cylinder (3,1,1); //schnurloch b
        }
        }
        rotate (112.5,0,0) {
            translate ([0,26,1]) {
                cylinder (3,1,1);//schnurloch a
        }
            translate ([0,29,1]) {
                cylinder (3,1,1); //schnurloch b
        }
        }
        rotate (-112.5,0,0) {
            translate ([0,26,1]) {
                cylinder (3,1,1);//schnurloch a
        }
            translate ([0,29,1]) {
                cylinder (3,1,1); //schnurloch b
        }
        }
    }
}
//deckscheibe

translate([21,0,1]) {
    cylinder (115,3,3);
}
translate ([-21,0,1]) {
    cylinder (115,3,3);
}
//stangen

rotate (45,0,0) {
   translate ([0,0,109]) {
    difference() {
        cube ([49,49,10],true);//platine
        rotate (-45,0,0) {
            translate([0,38,0]) {
                cube ([18,18,19],true);//ecke(y)
            }
            translate ([0,-38,0]) {
                cube ([18,18,19],true); //ecke(-y)
            }
            translate ([38,0,0,]) {
                cube ([18,18,19],true);//ecke (x)
            }
            translate ([-38,0,0]) {
                cube ([18,18,19],true);//ecke(-x)
            }
        }
    }
} //gps
translate ([0,0,98]) {
    difference() {
        cube ([49,49,10],true);//platine
        rotate (-45,0,0) {
            translate([0,38,0]) {
                cube ([18,18,19],true);//ecke(y)
            }
            translate ([0,-38,0]) {
                cube ([18,18,19],true); //ecke(-y)
            }
            translate ([38,0,0,]) {
                cube ([18,18,19],true);//ecke (x)
            }
            translate ([-38,0,0]) {
                cube ([18,18,19],true);//ecke(-x)
            }
        }
    }
}//temperatur
translate ([0,0,83]) {
    difference() {
            cube ([49,49,2],true);//platine
        rotate (-45,0,0) {
            translate([0,38,0]) {
                cube ([18,18,11],true);//ecke(y)
            }
            translate ([0,-38,0]) {
                cube ([18,18,11],true); //ecke(-y)
            }
            translate ([38,0,0,]) {
                cube ([18,18,11],true);//ecke (x)
            }
            translate ([-38,0,0]) {
                cube ([18,18,11],true);//ecke(-x)
            }
        }
    }
    translate([0,20,5])  {
    cube ([26,5,8],true); //pinleiste(y)
    }
    translate([0,-20,5])  {
    cube ([26,5,8],true); //pinleiste(-y)
    }
    translate([20,0,5])  {
    cube ([5,26,8],true); //pinleiste(x)
    }
    translate([0,0,2]) {
    cube ([34,34,2],true); //besetzter platz
    }
    translate([-23,11,0]) {
        cube ([5,5,8]); //stromanschluss-plastik-dingens
    }
}//computer(processor)
translate ([0,0,72]) {
    difference() {
            cube ([49,49,2],true);//platine
        rotate (-45,0,0) {
            translate([0,38,0]) {
                cube ([18,18,11],true);//ecke(y)
            }
            translate ([0,-38,0]) {
                cube ([18,18,11],true); //ecke(-y)
            }
            translate ([38,0,0,]) {
                cube ([18,18,11],true);//ecke (x)
            }
            translate ([-38,0,0]) {
                cube ([18,18,11],true);//ecke(-x)
            }
        }
    }
    translate([0,20,5])  {
    cube ([26,5,8],true); //pinleiste(y)
    }
    translate([0,-20,5])  {
    cube ([26,5,8],true); //pinleiste(-y)
    }
    translate([20,0,5])  {
    cube ([5,26,8],true); //pinleiste(x)
    }
    translate([0,0,2]) {
    cube ([34,34,5],true); //besetzter platz
    }
}//SDkarte
translate ([0,0,61]) {
    difference() {
            cube ([49,49,2],true);//platine
        rotate (-45,0,0) {
            translate([0,38,0]) {
                cube ([18,18,11],true);//ecke(y)
            }
            translate ([0,-38,0]) {
                cube ([18,18,11],true); //ecke(-y)
            }
            translate ([38,0,0,]) {
                cube ([18,18,11],true);//ecke (x)
            }
            translate ([-38,0,0]) {
                cube ([18,18,11],true);//ecke(-x)
            }
        }
    }
    translate([0,20,5])  {
    cube ([26,5,8],true); //pinleiste(y)
    }
    translate([0,-20,5])  {
    cube ([26,5,8],true); //pinleiste(-y)
    }
    translate([20,0,5])  {
    cube ([5,26,8],true); //pinleiste(x)
    }
    translate([0,0,2]) {
    cube ([34,34,2],true); //besetzter platz
    }
}//sender
//platinen

translate ([0,0,11]) {
    rotate (60,0,0) {
        difference() {
            cube([46,34,18],true);
            cylinder (18,4,8);
        }
    }
}
//staubsensor


rotate(-110,0,0) {
translate([-3,28,23]) {
     cube([18,1,42],true); //platine
    translate([0,4,9]) {
        cube ([8,8,8],true);//kamera-linse
    }
    translate ([-6,-8.5,-6]) {
        cube ([15,8,27]);//akku
    }
}
}//kamera

translate ([-6,-2.5,65.75]) {
    cube ([41,30,3],true);//lipo-akku1
}
translate ([-6,-2.5,79]) {
    cube ([41,30,3],true);//lipo-akku2
}
translate ([-6,-2.5,69.25]) {
    cube ([41,30,3],true);//lipo-akku3
}
translate ([-6,-2.5,91]) {
    cube ([41,30,3],true);//lipo-akku4
}
//akkus
}


rotate(-60,0,0) {
    translate ([0,0,0]) {
        difference () {
            cylinder (115,33,33); //aussenhuelle
            translate ([0,0,-0.5]) {
                cylinder (116,31,31);//hohlraum
            translate ([0,30,32]) {
                cube ([12,10,10],true);//guckloch kamera
            }
        }
        }
    }
}
//huelle
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

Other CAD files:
cansat3d-fertig.scad

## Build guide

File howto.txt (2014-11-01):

git				http://rogerdudler.github.io/git-guide/index.de.html

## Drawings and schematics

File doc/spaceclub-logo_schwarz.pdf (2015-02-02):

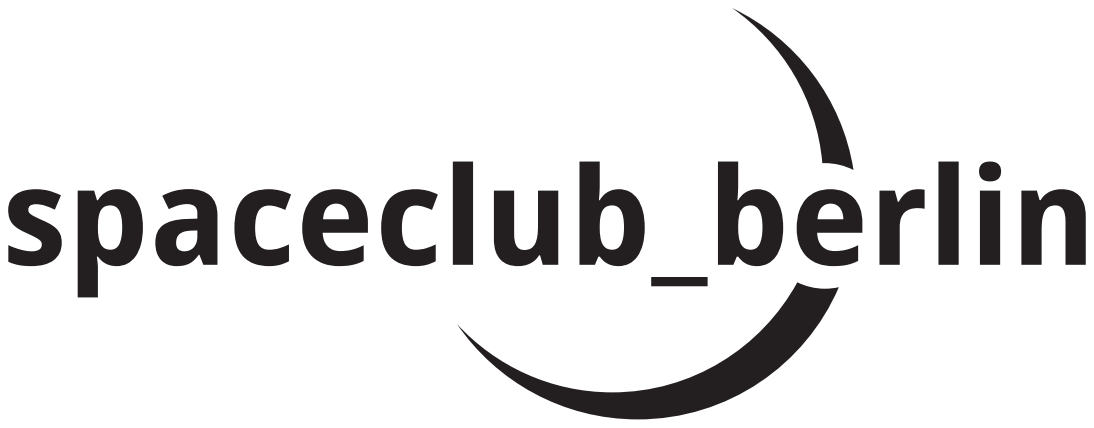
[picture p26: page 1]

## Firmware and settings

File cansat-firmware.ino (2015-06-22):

#include <Wire.h>
#include <Adafruit_Sensor.h>
#include <Adafruit_BMP085_U.h>
#include <Adafruit_LSM303_U.h>
#include <Adafruit_L3GD20_U.h>
#include <Adafruit_10DOF.h>
#include <SD.h>
#define beepPin 5 // digitaler D-Pin 5 für Beeper
#define SERPERATOR ","
#define tempNTCPin A2 // ext. Sensor NTC (2 Beine)
// NTC-sensor variables
#define NTC_Grad 18.1699	// The gradiant value for the NTC sensor
#define NTC_Off 21.0	// The offset value for the NTC sensor
int HIH4030_Pin = A8; //analog pin 8
const int chipSelect = 27;
#define dustPin A9 // angeschlossen an Pin A9
#define dustLEDPin 4

#define GroundPressureTestCount 10

/*********************** Assign a unique ID to the sensors ****************************/
Adafruit_LSM303_Accel_Unified accel = Adafruit_LSM303_Accel_Unified(30301);
Adafruit_LSM303_Mag_Unified mag = Adafruit_LSM303_Mag_Unified(30302);
Adafruit_BMP085_Unified bmp = Adafruit_BMP085_Unified(18001);
Adafruit_L3GD20_Unified gyro = Adafruit_L3GD20_Unified(20);
Adafruit_10DOF                dof   = Adafruit_10DOF();
/**************************************************************************************/
/*****************************Global Defines ******************************************/
float groundPressure = 0;
boolean wasAbove50m = false;
float accelX;
float accelY;
float accelZ;
float magX;
float magY;
float magZ;
float gyroX;
float gyroY;
float gyroZ;
float temp;
boolean readGPS = false;
// Dustsensor (2)
int dustValue = 0; // Wert der vom Dust Sensor kommt
float voltage = 0; // errechnete Voltzahl
float dustDensity = 0; // letztendliche Staubkonzentration
long lastGpsReadMillies = 0;
unsigned long  lastFullMillies = 0;
boolean doBeep = false;
unsigned long lastBeep = 0;

/**************************************************************************************/

void setup(){
  Serial.begin(19200);
  Serial1.begin(19200);
  for (int i= 16; i < 24; i++) {
    pinMode(i, OUTPUT);
    digitalWrite(i, HIGH);
  }
  pinMode(beepPin, OUTPUT);
  
  digitalWrite(16, LOW);
  delay (500);
  /* Initialise the sensors */
  if(!accel.begin()) {
    /* There was a problem detecting the ADXL345 ... check your connections */
    Serial.println(F("Ooops, no LSM303 detected ... Check your wiring!"));
    while(1);
  }
  
  digitalWrite(17, LOW);
  delay (500);
  if(!mag.begin()) {
    /* There was a problem detecting the LSM303 ... check your connections */
    Serial.println("Ooops, no LSM303 detected ... Check your wiring!");
    while(1);
  }
  digitalWrite(18, LOW);
  delay (500);
  if(!bmp.begin()) {
    /* There was a problem detecting the BMP085 ... check your connections */
    Serial.print("Ooops, no BMP085 detected ... Check your wiring or I2C ADDR!");
    while(1);
  }
  digitalWrite(19, LOW);
  delay (500);
  if(!gyro.begin()) {
    /* There was a problem detecting the L3GD20 ... check your connections */
    Serial.print("Ooops, no L3GD20 detected ... Check your wiring or I2C ADDR!");
    while(1);
  }
  digitalWrite(20, LOW);
  delay (500);

  
  float pressureSum = 0;
  for (int i = 0; i < GroundPressureTestCount; i++) {
    sensors_event_t preshureEvent;
    bmp.getEvent(&preshureEvent); 
    pressureSum += preshureEvent.pressure;
    Serial.print("groundpreshure = ");
    Serial.println (preshureEvent.pressure);
    delay(1000);
  }
  
  groundPressure = pressureSum / GroundPressureTestCount;
  Serial.print("GroundPressure=");
  Serial.println(groundPressure);
  
  Serial.println ("Secs,currentheight,pressure,Temp,Dustdensity,Temp.ext,humidity,GPS");
  Serial1.println ("Secs,currentheight,pressure,Temp,Dustdensity,Temp.ext,humidity,GPS");
  
  digitalWrite(21, LOW);
  delay (500);
  
  Serial3.begin(9600); // init GPS on Serial3
  Serial3.println("$PMTK314,0,0,0,1,0,0,0,0,0,0,0,0,0,0,0,0,0,0,0*29"); // only CGA output

  digitalWrite(22, LOW);
  delay (500);
  
  
  pinMode(chipSelect, OUTPUT);
  Serial.println("init card");
  if (!SD.begin(chipSelect)) {
    Serial.println("Card failed, or not present");
    // don't do anything more:
    return;
  }
  File myFile = SD.open("data.txt", FILE_WRITE);
  if (myFile) {
    Serial.print("File opened");
    myFile.println("-----------------------------------SNIP----------------------------------");
    myFile.println("Secs,currentheight,pressure,Temp,Dustdensity,Temp.ext,humidity,GPS"); 
    // close the file:
    myFile.close();
    Serial.println("done.");
  } else {
    // if the file didn't open, print an error:
    Serial.println("File couldnt be opened");
    return;
  }
  
  File my10DOFFile = SD.open("10dof.txt", FILE_WRITE);
  if (my10DOFFile) {
    Serial.print("File opened");
    my10DOFFile.println("-----------------------------------SNIP----------------------------------");
    my10DOFFile.println("accelx,accely,accelz,magx,magy,magz,gyrox,gyroy,gyroz,roll,pitch,heading"); 
    // close the file:
    my10DOFFile.close();
    Serial.println("done.");
  } else {
    // if the file didn't open, print an error:
    Serial.println("File couldnt be opened");
    return;
  }
  
  
  Serial.println("Card initialised");
  digitalWrite(23, LOW);
  delay (500);
  
  pinMode(dustLEDPin, OUTPUT);
  
  digitalWrite(beepPin, HIGH);
  delay (500);
  
  digitalWrite(beepPin, LOW);  
  
  // switch off all the led to save energy
  for (int i= 16; i < 24; i++) {
    digitalWrite(i, HIGH);
  }
  
}

  
void loop() {
  read10dof();
  
  if (doBeep && lastBeep < millis()) {
      digitalWrite(beepPin, !digitalRead(beepPin));
      lastBeep = millis() + 200;
  }
//  Serial.print((lastFullMillies + 1000));
//  Serial.print(" ");
//  Serial.println(millis());
  if ((lastFullMillies + 1000) < millis()) {
    // read out all the sensor values
    sensors_event_t preshureEvent;
    float currentHeight;
    bmp.getEvent(&preshureEvent); // get pressure
    float temperature; // Temp
    bmp.getTemperature(&temperature); // write temp into float
    float pressure = preshureEvent.pressure; // write current pressure to float
    dustDensity = readDustSensor();// read dust value from sensor
  
    float externalTemperature = getTemperatureExtern(tempNTCPin);// read NTC
    float humidity = getHumidity(temperature);// read humiditySensor

    // calculate the current height
    currentHeight = bmp.pressureToAltitude(groundPressure,preshureEvent.pressure); // calculating the altitude from pressure
    if (!wasAbove50m && currentHeight > 50) {
      wasAbove50m = true;   
    }
    // check if passed the boarder and switch on beeping if passed
    if (wasAbove50m && currentHeight < 50) {
      doBeep = true;
    }
  
    // read out gps data
    String gpsString = "";
    if ((millis() - lastGpsReadMillies) > 1000) {
      String temp = "";
      if (!readGPS) {
        temp = GetGGA();
        lastGpsReadMillies = millis();
        if (!temp.equals("")) {
          gpsString += temp;
        }
      }
    }
    // save all the values
    saveData(currentHeight, preshureEvent.pressure, temperature, dustDensity, externalTemperature, humidity, gpsString);
    lastFullMillies = millis();
  }
  delay(100);

}

void read10dof () {
// read out all the sensor values
  sensors_event_t accEvent; 
  accel.getEvent(&accEvent);// get acceleration data
  sensors_event_t magEvent;
  mag.getEvent(&magEvent); // get magnetic vector values
  sensors_event_t gyroEvent;
  gyro.getEvent(&gyroEvent); // get gyrocope values
  sensors_event_t preshureEvent;


  File my10DOFFile = SD.open("10dof.txt", FILE_WRITE);
  if (my10DOFFile) {
    my10DOFFile.print(SERPERATOR);
    my10DOFFile.print(accEvent.acceleration.x);
    my10DOFFile.print(SERPERATOR);
    my10DOFFile.print(accEvent.acceleration.y);
    my10DOFFile.print(SERPERATOR);
    my10DOFFile.print(accEvent.acceleration.z);
    my10DOFFile.print(SERPERATOR);
    my10DOFFile.print(magEvent.magnetic.x);
    my10DOFFile.print(SERPERATOR);
    my10DOFFile.print(magEvent.magnetic.y);
    my10DOFFile.print(SERPERATOR);
    my10DOFFile.print(magEvent.magnetic.z);
    my10DOFFile.print(SERPERATOR);
    my10DOFFile.print(gyroEvent.gyro.x);
    my10DOFFile.print(SERPERATOR);
    my10DOFFile.print(gyroEvent.gyro.y);
    my10DOFFile.print(SERPERATOR);
    my10DOFFile.print(gyroEvent.gyro.z);
    my10DOFFile.print(SERPERATOR);
    sensors_vec_t   orientation;
    if (dof.fusionGetOrientation(&accEvent, &magEvent, &orientation))
    {
      my10DOFFile.print(orientation.roll);
      my10DOFFile.print(SERPERATOR);
      my10DOFFile.print(orientation.pitch);
      my10DOFFile.print(SERPERATOR);
      my10DOFFile.print(orientation.heading);
      my10DOFFile.print(SERPERATOR);
    } else {
      // if not print empty
      my10DOFFile.print(SERPERATOR);
      my10DOFFile.print(SERPERATOR);
      my10DOFFile.print(SERPERATOR);
      
    }
    
    
    my10DOFFile.println();
    my10DOFFile.close();
  } else {
    // if the file didn't open, print an error:
    Serial.println("10DOF file couldn't be opened");
    return;
  }
  


}

float readDustSensor() {
  float currentDustDensity;
  digitalWrite(dustLEDPin, LOW); // switch dust-LED on
  delayMicroseconds (280);
  dustValue=analogRead(dustPin); // read dust value
  delayMicroseconds (40);
  digitalWrite(dustLEDPin, HIGH); // switch dust-LED off
  delayMicroseconds (9680); // cooldown
  voltage = dustValue *0.0048875; // convert Volt to dustValue
  if (voltage <= 3.5) { // nicht Linearität des Sensors beachten
    currentDustDensity = voltage /7.5;
  } else {
    currentDustDensity = (voltage-3.5)*2 +0.4;
  }
  return currentDustDensity;
}

String GetGGA() {
  String gps_output = "";
  boolean GGAready = false;
  boolean start = false;
  int inByte = 0;
  char inChar;
  readGPS = true;
  while (!GGAready) {
    // Serial.println(millis());
    if (Serial3.available()) {
      inChar = Serial3.read();
      inByte = int(inChar);
      //Serial.print(inChar); // Debug Ausgabe
      //Serial.print(inByte); // Debug Ausgabe
      //Serial.print(", "); // Debug Ausgabe
      if (start) {
        if (inByte==13) { 
          GGAready=true;
        } else {
        gps_output += inChar;
        }
      } else { 
        if (inByte==10) {
          start = true;
        }
      }// Ende if (start)
    } // Ende if (available)
  }// Ende while
  readGPS = false;
  return(gps_output);
}


void saveData(float currentHeight, float pressure, float temperature, float dustDensity, float externalTemp, float humidity, String gpsString) {

  // open file on SD card              
  File myFile = SD.open("data.txt", FILE_WRITE);
              
  // print all the data to each channel
  printData(millis()/1000, myFile);
  printData(SERPERATOR, myFile);
  printData(currentHeight, myFile);
  printData(SERPERATOR, myFile);
  printData(pressure, myFile);
  printData(SERPERATOR, myFile);
  printData(temperature, myFile);
  printData(SERPERATOR, myFile);
  printData(dustDensity, myFile);
  printData(SERPERATOR, myFile);
  printData(externalTemp, myFile);
  printData(SERPERATOR, myFile);
  printData(humidity, myFile);
  printData(SERPERATOR, myFile);
  printData(gpsString, myFile);  
  endLine(myFile);
  
  // close the file and if ther is a problem report it
  if (myFile) {
    myFile.close();
  } else {
    Serial.println("File couldnt be opened");
    Serial1.println("File couldnt be opened");
  }
}

// print a String to each channel
void printData (String data, File myFile) {
  Serial.print(data);
  Serial1.print(data);
  if (myFile) {
    myFile.print(data);
  }
}

// print a float to each channel
void printData (float data, File myFile) {
  Serial.print(data);
  Serial1.print(data);
  if (myFile) {
    myFile.print(data);
  }
}

// print carriage return to each channel
void endLine (File myFile) {
  Serial.println();
  Serial1.println();
  if (myFile) {
    myFile.println();
  }
}

float getTemperatureExtern(int pin){
  float volt = Bit2Volt(pin); // liest pin ein
  float Temp=NTC_Grad*volt-NTC_Off; // umrechnen Volt nach Grad Celcius
  return Temp; // zurueckgeben
}

float Bit2Volt(int n){ // Funktion zum Lesen und umwandeln
  int raw = analogRead(n); // Messdaten von pin 'n' lesen
  float volt = (float)raw*5.000/1023; // Umrechnung für Volt
  return volt; // zurückgeben der Voltzahl
}

float getHumidity(float degreesCelsius){
  //caculate relative humidity
  float supplyVolt = 5.0;

  // read the value from the sensor:
  int HIH4030_Value = analogRead(HIH4030_Pin);
  float voltage = HIH4030_Value/1023. * supplyVolt; // convert to voltage value
  //voltage = 1.8;
  // convert the voltage to a relative humidity
  // - the equation is derived from the HIH-4030/31 datasheet
  // - it is not calibrated to your individual sensor
  //  Table 2 of the sheet shows the may deviate from this line
  float sensorRH = 161.0 * voltage / supplyVolt - 25.8;
  float trueRH = sensorRH / (1.0546 - 0.0026 * degreesCelsius); //temperature adjustment 
  return trueRH;
}

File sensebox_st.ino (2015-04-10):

/*******************************************************************************************
 * Programm für die Aufzeichung von Sensebox Sensoren auf eine SD Karte                    *
 * Autor: Steffen Janke (Zuarbeit Hersteller)                                              *
 * Version: 1.10                                                                           *
 * Datum letzte Änderung: 23.07.2014                                                       *
 *******************************************************************************************/
 
//libraries to include
#include <SD.h>
#include <Wire.h>
#include <DHT.h>
#include <Barometer.h>

#define serialBaud 9600

//SD Card Pin
#define SDCARD_CS 4

//Define analog ports used by sensors
#define LightData A1    // parameters for Light Sensor
#define SoundData A0    // parameters for Sound-Sensor
#define DHTPIN A2       // parameters for DHT-Sensor

// enable/disable sensors
#define dhtEnabled true
#define LightEnabled true
#define SoundEnabled true
#define csvColumns "Zeit in s;Druck;Hoehe; Temperatur (p); Temperatur (t);Luftfeuchte;Licht;Licht (K);Lautstaerke"

// first time variable
boolean firstTime = true;
float pressu;
float altim;

File sdfile;


//Sensor instances
DHT dht(DHTPIN, DHT11);
Barometer myBarometer;

//Variables for time sync and upload intervall
const unsigned long postingInterval = 1000; //1 sek
long int lastConnected = 0;
boolean uploadSuccess = false;

void setup()
{
  //Start serial port
  Serial.begin(serialBaud);
  Serial.println("Initialisiere SD Karte...");
  if (!SD.begin(SDCARD_CS)) 
  {
    Serial.println("Initialisierung fehlgeschlagen!");
    return;
  }
  Serial.println("Initialisierung gelaufen.");
  if (SD.exists("WETTER.CSV")) 
  {
    Serial.print("WETTER.CSV existiert->wird geloescht!");
    do 
    { // solange versuchen zu löschen, bis weg ist
      Serial.print("."); 
      SD.remove("WETTER.CSV");
      delay(100);
    } while (SD.exists("WETTER.CSV"));
    Serial.println(); 
  }  
  Serial.println("Oeffne Wetter.txt zum Schreiben"); 
  sdfile = SD.open("WETTER.CSV", O_CREAT | O_WRITE | O_APPEND);
  if (sdfile) 
  {
    Serial.println("WETTER.CSV offen");
  } else 
  {
    Serial.println("Fehler beim Oeffnen der WETTER.CSV");
  }
  //initialize barometer and DHT sensors
  myBarometer.init();
  dht.begin();
}

void loop()
{
  String output = "";
//  if((millis() - lastConnected > postingInterval)) 
  if(sdfile && (millis() - lastConnected >= postingInterval)) 
  {
    lastConnected = millis();
    char time[20];
    dtostrf(lastConnected/1000, 0, 0, time);
    char humidity[20];
    dtostrf(dht.readHumidity(), 0, 2, humidity);
    char temperature[20];
    dtostrf(dht.readTemperature(), 0, 2, temperature);
    char temperature2[20];
    dtostrf(myBarometer.bmp085GetTemperature(myBarometer.bmp085ReadUT()), 0, 2, temperature2);
    char pressure[20];
    pressu = myBarometer.bmp085GetPressure(myBarometer.bmp085ReadUP());
    dtostrf(pressu, 0, 2, pressure);
    altim = myBarometer.calcAltitude(pressu);
    char hoehe[20];
    dtostrf(altim, 0, 1, hoehe);

    // build one csv output string
    output += time;
    output += ";";
    output += pressure;
    output += ";";
    output += hoehe;
    output += ";";
    output += temperature2;
    output += ";";
    
    if (dhtEnabled) 
    {
       output += temperature;
       output += ";";
       output += humidity;
    } else { output += "-;-"; }
    output += ";";
    if (LightEnabled) 
    {
      int sensorValue = analogRead(0); 
      float Rsensor;
      sensorValue = analogRead(LightData);
      Rsensor=(float)(1023-sensorValue)*10/sensorValue;
      char rs[20];
      dtostrf(Rsensor, 0, 2, rs);
      output += sensorValue;
      output += ";";
      output += rs;
    }else { output += "-"; }
    output += ";";
    if (SoundEnabled) 
    {  
      output += analogRead(SoundData);
    } else { output += "-"; }
    output += ";";

    postData(output);
  }
}

//Method for posting a measurement to OSM server
void postData(String txt)
{  
  if (firstTime) 
  {
   // set the first time variable to false
    firstTime = false;
    // serial output
    Serial.println(csvColumns);
    // sd card output
    sdfile.println(csvColumns);
  }

  Serial.println(txt);
  sdfile.println(txt);
  sdfile.flush();
}

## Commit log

2014-11-02 GitHub for Windows
    in Software eingebaut, und in README.md kurz beschrieben.
2014-11-02 add sensors
2014-11-04 github tutorial
    added a github tutorial with samples
2014-11-08 adapter first draft
    [ArduinoMega2Cansat.fzz]
2014-11-08 fix directions
    [ArduinoMega2Cansat.fzz]
2014-11-09 added leds to pcb
    [ArduinoMega2Cansat.fzz]
2014-11-11 added delete und exclude from commit to tutorial
2014-11-18 neue Linksammlung
    freut sich auf erweiterungen von Sylvia und alles anderen :
2014-11-25 test
    nicht wirklich was
2014-11-27 Funktionen des CanSat
    kann ergänzt werden
2014-11-27 Vorschlag für die Anmeldung
    habe hier mal meine vorschläge in deutsch verfasst
2014-12-01 Revert "Vorschlag für die Anmeldung"
    This reverts commit 69c447c7c7ddcf03e33b63d3132172a0c7c6d73a.
2014-12-01 CanSat 2015 ESA Anmeldung Englisch
    Hier ist die Englische Version
2014-12-01 Anmeldung Formatierung geändert
    nun auch als docx und pdf
2014-12-03 Neuer Antrag
    Hier ist der überarbeitete Antrag. Überfliegt ihn doch nochmal damit ich
    ihn dann an Sylvi schicken kann
2015-01-22 Vorstellung spaceclub und orbitall auf englisch von jasper
2015-01-26 DHT11 Sensor zugefügt, als Alternative zum DHT22
    warum, findet es selber raus.
2015-04-10 Sensebox Programm vom August 2014
    das fertige Sensebox Programm, vor allem für das Auslesen des Barometer
    Sensors wichtig!! Reihenfolge im Programm beachten!!!!!
2015-05-30 added firmware and 3d modell
    [cansat3d.scad]
2015-06-02 latest version with working sd and dust sensor
2015-06-09 code beautifying and added provisional values for missing sensors
    [cansat-firmware.ino]
2015-06-11 cansat-3d-erweitert.scad
    3d modell des cansats mit der bodenplatte (löcher für stangen von 1.5 auf 2 vergrößert zum testen) für den alten cansat. am neuen cansat hat sich nichts geändert.
    [cansat-3d-erweitert.scad]
2015-06-12 added test data from bike ride
    [DATA.csv]
2015-06-16 Create tester for new humidity sensor
2015-06-19 bodenplatte-sensorloch.scad
    so hier ist die bodenplatte für den neuen cansat mit vergrößerten stangenlöchern
    [bodenplatt-sensorloch.scad]
2015-06-20 added pitch roll and heading
2015-06-21 firmware-cansat-header-pitch-roll-yaw.ino
    headerline in serial verändert, added headerline in serial1
